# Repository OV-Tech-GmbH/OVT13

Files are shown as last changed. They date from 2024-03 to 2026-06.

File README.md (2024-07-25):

# OVT13
Open-source thin-and-light 13" laptop
## Table of contents

1. Electronics
   - Keyboard PCB
   - Webcam PCB
   - Trackpad PCBs
2. Mechanical
   - Keyboard
3. Software
   - Keyboard firmware and source files

## Details of content

1. Electronics
   - Keyboard PCB: Render01<br /> <br /> 
***General description:*** <br /> <br /> This module is a separate standalone and thinly-designed electromechanical keyboard for the open-source laptop. It provides a distinct hardware abstraction via USB2.0 connectivity to simplify integration into a laptop or computer system. An RP2040 microcontroller constantly evaluates the states of the keyswitches and controls the lightning. Regarding the power supply only a voltage of 5V DC is needed to completly supply the electronics, all other voltages for digital logic and LED-driving are being generated on the PCB. Once connected to an USB Host in a computer system, the microcontroller acts as an USB Device and registers itself as an USB HID keyboard device. With this configuration no custom drivers are needed which contributes to an os-independend (Windows, Linux, etc.) and timeless integration concept. The firmware of the microcontroller is based on the open-source keyboard framework QMK. Once an USB-connection is established, standard scancodes are being transmitted to the computer system which then will be mapped into keycodes. The hardware connectivity to the mainboard of the laptop is realized over an spring-header connector receptable which includes all electrical signals and the power supply. For the firmware to load onto the RP2040, only one pin of the spring header receptable must change its logical state. The RP2040 register itself as an USB-memory device which then can be accessed via the os` filesystem. It is possible to load the firmware file per drag&drop onto the microcontroller. <br /> <br /> 
***Electrical specification***<br /> <br /> 
__PCB front view__
OV_Tech_KB-PCB-R02_3DFront
The PCB-front consists of the keyswitches from the manufacturer Khail. The design integrates a complete set of keys without the numerical part. Keycaps can be assembled on top of the keyswitches.
Inside the keyswitches there is a transparent cabin to integrate LED components and other small components like the anti-ghosting diode. Per keyswitch a white LED and an RGB LED is placed to keep the option to build a keyboard with either white backlightning or RGB backlightning. OV_Tech_KB-PCB-R02_3DCutoutTopComponentPlacement
<br /><br /> __PCB back view__ <br />
On the backside of the PCB there are all remaining components located. The remaing components include the microcontroller RP2040 and its peripheral circuitry, voltage generation, ESD-protection and other parts of the keyswitch matrix.
OV_Tech_KB-PCB-R02_3DBack <br />
<br /> __PCB layerstack and routing__ <br /> The Layerstack consists four layers of copper and it is taken from the 4-Layer JLCPCB stackup JLC04161H-7628. An impedance profile 90Ohms is included for the USB connection. The layerstack looks as follows: Top-layer: Signal, Mid1-layer: GND, Mid2-layer PWR/GND, Bottom-layer: Signal OV_Tech_KB-PCB-LayerstackWithImpedanceProfile
On the top layer all signals and power supplies regarding the LED-backlightning are routed:
OV_Tech_KB-PCB-R02_TopLayer
The Mid1-layer includes a continuous ground plane to provide good electrical characteristics. The Mid2-layer is a mix of power plane distribution and ground islands, especially for the dense placement of the microcontroller and surrounding circuitry:
OV_Tech_KB-PCB-R02_MidLayer2PWRf
On the bottom layer consist of the routing of the keyswitch matrix, the microcontroller and the remaining circuitry.
OV_Tech_KB-PCB-R02_BottomLayer

   - Trackpad PCBs:<br /> <br /> 
***General description:***<br /> <br /> The design of the trackpad module consists of two printed circuit boards. The first one consists of the touch-sensitive matrix which, can be influenced by the user. In order to keep variations and negative impact factors away from the matrix, the touch sensing IC and its digital communication partner are located on an evaluation board. Both boards are connected via an flex-pcb cable section so the touch IC can to read the sensing matrix.<br /> <br /> Trackpad_Sensor_Eval_assembled
<br /> <br />
__1. Trackpad sensor PCB electrical specification:__<br /> <br />
The top side of the PCB consists of touch-sensitive elements in the form of diamonds arranged in rows and columns. The gaps between the diamonds form capacitive elements that can be controlled and thus read by the touch IC. The capacitive elements generate an electric field, that is deflected when the user`s finger approaches. The change in the field and thus the resulting capacitance and charge can be measured and converted into a finger position sensor. <br /> <br />
grafik
<br /> <br />
On the backside of the pcb a flex pcb connector and a snap dome are located. The flex connector is used to connect the board to another board on which a touch IC is located via a flex cable. The snap dome is being used to generate the function of a button press. When pressed, the entire row and colum is shorted and the rapid change in capacitance and therefore charge is recognised and interpreted as a button press. <br /> <br />
grafik
<br /> <br />__2. Trackpad evaluation PCB electrical specification:__<br /> <br />
This PCB is designed as a flex PCB with two stiffened sections. The section where all the components are located is fitted with a FR4-stiffener. The section designed as a flex cable contains no stiffeners in order to utilise the flexibility of a flex cable. The last section is the connector tongue itself and the stiffener is made out of polyimide to fulfil the thickness insertion requierements of the ffc-connector on the trackpad PCB.
<br /> <br />Trackpad Evalboard Board Section View
<br /> <br />
The evaluation board is used to collect trackpad touch data and turn it into an USB HID mouse. This level of integration abstracts the custom interface to a simple USB connection without the need for special drivers or hardware to utilise the touch data. The IQS9150 IC performs the sampling and processing of the trackpad touches and snapdome clicks and reports the data to an RP2040, which performs some further processing, such as interpreting a click event as a left or right mouse button click. The RP2040 streams the touch data in USB HID mouse format to an USB host and thus acts as an I2C USB bridge. Additional connections for programming and evaluating the two ICs and other devices such as test buttons are provided on the board for development purposes. The final board will contain only the two ICs, some necessary external circuitry and an USB connection. This makes integration into the laptop easy and follows the concept of a timeless and modular design.
<br /> <br />
Trackpad Evalboard Board 3D view<br /> <br />

3. Mechanical
   - Keyboard: -

4. Software
   - Keyboard PCB: The firmware of the keyboard was created using the framework QMK. The framework provides all basic keyboard functions such as matrix scanning, USB communication, lightning and much more. Therefore, only one module of the keyboard project has been created for the specific design of the keyboard. Minor modifications were made to the QMK core to compile the firmware for the RP2040 microcontroller. A standard English keyboard layout (QWERTY) was used. Details of the code project can be found in the subfolder for the keyboard software.

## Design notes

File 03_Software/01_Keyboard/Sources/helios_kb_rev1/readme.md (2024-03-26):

# helios_kb_rev1

helios_kb_rev1

*A short description of the keyboard/project*

* Keyboard Maintainer: [ThomasL](https://github.com/ThommyL34)
* Hardware Supported: *The PCBs, controllers supported*
* Hardware Availability: *Links to where you can find this hardware*

Make example for this keyboard (after setting up your build environment):

    make helios_kb_rev1:default

Flashing example for this keyboard:

    make helios_kb_rev1:default:flash

See the [build environment setup](https://docs.qmk.fm/#/getting_started_build_tools) and the [make instructions](https://docs.qmk.fm/#/getting_started_make_guide) for more information. Brand new to QMK? Start with our [Complete Newbs Guide](https://docs.qmk.fm/#/newbs).

## Bootloader

Enter the bootloader in 3 ways:

* **Bootmagic reset**: Hold down the key at (0,0) in the matrix (usually the top left key or Escape) and plug in the keyboard
* **Physical reset button**: Briefly press the button on the back of the PCB - some may have pads you must short instead
* **Keycode in layout**: Press the key mapped to `QK_BOOT` if it is available

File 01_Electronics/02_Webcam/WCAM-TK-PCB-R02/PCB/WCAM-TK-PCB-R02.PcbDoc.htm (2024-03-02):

Reporting Options

# File in Newer Format

Date | : | 06.11.2023
Time | : | 02:03:40
Filename | : | C:\Users\Lukas\OV Tech GmbH\OV Tech GmbH - Cloud\02_Projects\00_Helios\01_Elektronik\01_Module\02_Webcam\WCAM-TK-PCB-R02\PCB\WCAM-TK-PCB-R02.PcbDoc

Version | Warning
Release 23.6 | CAUTION - The PCB document contains Footprint parameters. These will be lost when opening the document in a version of Altium Designer that does not support this functionality.

This file was generated by a later version of the software

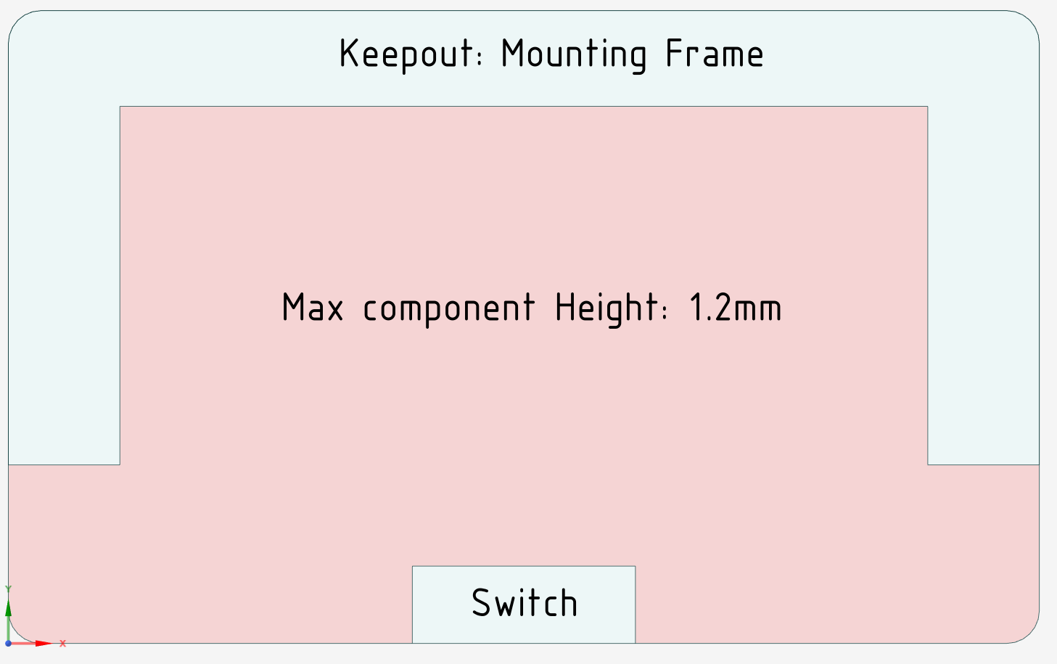
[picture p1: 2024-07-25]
01_Electronics/03_Trackpad/Trackpad sensor/TP-SENSOR-R01/MCAD EXCHANGE/Trackpad_Keepout Zones.png

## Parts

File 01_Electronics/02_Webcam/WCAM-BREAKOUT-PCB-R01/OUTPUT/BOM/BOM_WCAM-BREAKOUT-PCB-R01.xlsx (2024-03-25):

Designator | Quantity | Comment | Manufacturer 1 Prt. Nr. | Manufacturer 2 | Manufacturer 2 Prt. Nr.
C1, C2, C3, C6, C7, C8, C9, C10, C11, C12, C14, C15, C16 | 13 | 1µF 25V | GRM155R61E105KE11D | Walsin | 0402X105K250CT
C4, C5 | 2 | 470nF 25V | GRM155R61E474KE01D | Walsin | 0603X474K250CT
C13 | 1 | 470nF 10V | LMK063BBJ474KPLF | TDK | C0603X5R1A474M030BC
D1, D2 | 2 | ESD7504MUTAG | ESD7504MUTAG
J1 | 1 | SFW15R-1STE1LF | SFW15R-1STE1LF
J2, J3, J5 | 3 | 61300311121 | 61300311121
J4 | 1 | 61301621021 | 61301621021
L1, L2, L3 | 3 | 90Ohm 100mA | DLM0NSM900HY2D
Q1 | 1 | SSM3J56ACT,L3F | SSM3J56ACT,L3F
Q2 | 1 | SSM3K15ACT,L3F | SSM3K15ACT,L3F
Q3 | 1 | DMG1024UV-7 | DMG1024UV-7
Q4, Q5, Q6, Q7, Q8, Q9, Q10, Q11, Q12 | 9 | PMZ130UNEYL | PMZ130UNEYL
R1, R2, R4, R9, R30, R31, R34, R35, R38, R39, R40, R43, R46, R60, R61, R66, R67 | 17 | 0Ohm 1% | CR0402AJ/-000GAS | YAGEO | AC0402FR-070RL
R3, R8 | 2 | 15k 1% | CRCW040215K0FKED | YAGEO | RT0402FRE0715KL
R5, R7, R12, R16, R22, R23, R32, R63 | 8 | 1.5k 1% | CRCW04021K50FKED | YAGEO | RC0402FR-131K5L
R6 | 1 | 240R 1% | CRCW0402240RFKEDC | YAGEO | RC0402FR-13240RL
R10, R11 | 2 | 2.2k 1% | CRCW04022K20FKED | Panasonic | ERJ-2RKF2201X
R13, R18, R20, R24, R25, R29, R47, R59, R65 | 9 | 100R 1% | CRCW0402100RFKEDC | YAGEO | RC0402FR-07100RL
R14, R17, R19, R21, R26, R27, R28, R33, R36, R37, R41, R42, R50, R53, R54, R64, R68 | 17 | 10k 1% | CRCW040210K0FKEDC | YAGEO | RT0402FRE0710KL
R15 | 1 | 27R 1% | RC0402FR-0727RL | TE Connectivity Passive Product | CRGCQ0402F27R
R44, R45, R62 | 3 | 47k 1% | CRCW040247K0FKEDC | YAGEO | RT0402FRE0747KL
R48, R49, R51, R52, R55, R56 | 6 | 200 1% | ERJ-2RKF2000X | Bourns | CR0402-FX-2000GLF
U1 | 1 | OV02740-H34A-Z | OmniVision
U2 | 1 | TLV74018PDQNR | TLV74018PDQNR
U3 | 1 | TLV74012PDQNR | TLV74012PDQNR
U4 | 1 | TLV74028PDQNR | TLV74028PDQNR
U5 | 1 | ECS-2520MV-240-BN-TR | ECS-2520MV-240-BN-TR
U6, U8 | 2 | 74HC2G14GW-Q100 | 74HC2G14GW-Q100
U7 | 1 | TCAL9539RTWR | TCAL9539RTWR

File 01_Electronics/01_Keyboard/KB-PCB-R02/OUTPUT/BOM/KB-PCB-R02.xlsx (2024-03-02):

Designator | Quantity | Manufacturer 1 Prt. Nr. | Manufacturer 2 Prt. Nr.
C1, C3, C5, C6, C7, C8, C9, C12, C13, C14, C15, C18, C22, C26, C27, C28, C29, C30, C31, C32, C33, C34, C35, C36, C37, C38, C39, C40, C41, C42, C43, C44, C45, C46, C47, C48, C49, C50, C51, C54, C55, C56, C57, C58, C59, C60, C61, C62, C63, C64, C65, C66, C67, C68, C69, C70, C71, C72, C73, C74, C75, C76, C77, C78, C79, C80, C81, C82, C83, C84, C85, C86, C87, C88, C89, C90, C91, C92, C93, C94, C95, C96, C97, C98, C99, C100, C101, C102, C103, C104, C105, C106, C107, C108, C109, C115, C116 | 97 | KGM05AR71C104KH | EMK105B7104KV-F
C2, C4, C25 | 3 | CL05A105KO5NNNC | EMK105BJ105KV-F
C10, C11 | 2 | CL21A106KOQNNNG | C0805C106K8PAC7210
C16, C17 | 2 | QSCF500Q270G1GV001T | GJM1555C1H270GB01D
C19, C110, C111, C112, C113, C114 | 6 | GCM1555C1H331FA16J | C0402C331J5GACAUTO
C20, C23 | 2 | GRM21BR61E226ME44K | CC0805MKX5R8BB226
C21, C24, C52, C53 | 4 | GRM188R61E106KA73J | CL10A106MA8NRNC
D1, D2, D3, D4, D5, D6, D7, D8, D9, D10, D11, D12, D13, D14, D15, D16, D17, D18, D19, D20, D21, D22, D23, D24, D25, D26, D27, D28, D29, D30, D31, D32, D33, D34, D35, D36, D37, D38, D39, D40, D41, D42, D43, D44, D45, D46, D47, D48, D49, D50, D51, D52, D53, D54, D55, D56, D57, D58, D59, D60, D61, D62, D63, D64, D65, D66, D67, D68, D69, D70, D71, D72, D73, D74, D75, D76, D77, D78, D79, D80 | 80 | BAT54LS-QYL
D81, D82, D83, D84, D85, D86, D87, D88, D89, D90, D91, D92, D93, D94, D95, D96, D97, D98, D99, D100, D101 | 21 | PESD5V5C1UL
J2_DBG | 1 | SM05B-SRSS-TB
L1 | 1 | MPL-AL4020-3R3
LED1, LED2, LED3, LED4, LED5, LED6, LED7, LED8, LED9, LED10, LED11, LED12, LED13, LED14, LED15, LED16, LED17, LED18, LED19, LED20, LED21, LED22, LED23, LED24, LED25, LED26, LED27, LED29, LED30, LED31, LED32, LED33, LED34, LED35, LED36, LED37, LED38, LED39, LED40, LED41, LED42, LED43, LED44, LED45, LED46, LED47, LED48, LED49, LED50, LED51, LED52, LED53, LED54, LED55, LED57, LED58, LED59, LED60, LED61, LED62, LED63, LED64, LED65, LED66, LED67, LED68, LED69, LED70, LED71, LED72, LED73, LED74, LED75, LED76, LED77, LED78, LED79, LED80, LED81, LED82, LED83, LED85 | 82 | HL-PT-1608H322W-L
LED86, LED87, LED88, LED89, LED90, LED91, LED92, LED93, LED94, LED95, LED96, LED97, LED98, LED99, LED100, LED101, LED102, LED104, LED105, LED106, LED107, LED108, LED109, LED110, LED111, LED113, LED114, LED115, LED116, LED117, LED118, LED119, LED120, LED122, LED123, LED124, LED125, LED126, LED127, LED128, LED129, LED130, LED131, LED132, LED133, LED134, LED135, LED136, LED137, LED138, LED139, LED140, LED141, LED142, LED143, LED144, LED145, LED146, LED147, LED148, LED149, LED150, LED151, LED152, LED153, LED154, LED155, LED156, LED157, LED158, LED159, LED160, LED161, LED162, LED163, LED164, LED165, LED166, LED167, LED168, LED169 | 81 | SK6805-EC15
Q2 | 1 | PMG85XP,115
Q3, Q4, U4 | 3 | SSM3K15ACT,L3F
R1, R2 | 2 | RC0402FR-0727RL | CRGCQ0402F27R
R3, R4, R5, R6, R7, R8, R49 | 7 | CRCW040210K0FKEDC | RT0402FRE0710KL
R9, R11 | 2 | CRCW04021K00FKEDC | RT0402FRE131KL
R10 | 1 | CRCW040210K0FKEDC | RT0402FRE0710KL
R12, R13, R14, R15, R16, R17, R18, R19 | 8 | CR0402AJ/-000GAS | AC0402FR-070RL
R20, R21, R63 | 3 | CRCW0402100KFKEDC | RC0402FR-07100KL
R22, R23, R24, R25, R26, R27, R28, R29, R30, R31, R32, R33, R34, R35, R36, R37, R38, R39, R40, R41, R42, R43, R44, R45, R46, R47, R48 | 27 | RC0603FR-07113RL | ERJ-3EKF1130V
R50, R51, R57, R60, R64, R65 | 6 | CRCW0402100RFKEDC | RC0402FR-07100RL
R52, R53, R55, R59, R66, R168 | 6 | CRCW040247K0FKEDC | RT0402FRE0747KL
R54 | 1 | ERJ-3EKF88R7V | CR0603-FX-88R7ELF
R56 | 1 | CRCW0402130KFKED | CRCW0402750KFKEDC
R58 | 1 | CR0402-FX-6802GLF | SFR01MZPJ683
R61, R62, R67, R68, R69, R70, R71, R72, R73, R74, R75, R76, R77, R78, R79, R80, R81, R82, R83, R84, R85, R86, R87, R88, R89, R90, R91, R92, R93, R94, R95, R96, R97, R98, R99, R100, R101, R102, R103, R104, R105, R106, R107, R108, R109, R110, R111, R112, R113, R114, R115, R116, R117, R118, R119, R120, R121, R122, R123, R124, R125, R126, R127, R128, R129, R130, R131, R132, R133, R134, R135, R136, R137, R138, R139, R140, R141, R142, R143, R144, R145, R146 | 82 | CRCW0402470RFKED | RC0402FR-13470RL
R147, R148, R149, R150, R151, R152, R153, R154, R155, R156, R157, R158, R159, R160, R161, R162, R163, R164, R165, R166, R167 | 21 | ERJ-2RKF3000X | SFR01MZPJ301
SW1, SW2, SW3, SW4, SW5, SW6, SW7, SW8, SW9, SW10, SW11, SW12, SW13, SW14, SW15, SW16, SW17, SW18, SW19, SW20, SW21, SW22, SW23, SW24, SW25, SW26, SW27, SW28, SW29, SW30, SW31, SW32, SW33, SW34, SW35, SW36, SW37, SW38, SW39, SW40, SW41, SW42, SW43, SW44, SW45, SW46, SW47, SW48, SW49, SW50, SW51, SW52, SW53, SW54, SW55, SW56, SW57, SW58, SW59, SW60, SW61, SW62, SW63, SW64, SW65, SW66, SW67, SW68, SW69, SW70, SW71, SW72, SW73, SW74, SW75, SW76, SW77, SW78, SW79, SW80, SW81 | 81 | CPG1316S01D02
U1 | 1 | RP2040
U2 | 1 | TLV74033PDQNR
U3 | 1 | W25Q16JVUXIQ
U5 | 1 | MP3438
U6, U7 | 2 | 74HC2G14GV-Q100H
XTAL1 | 1 | H130B-12.000-18-3030-TR

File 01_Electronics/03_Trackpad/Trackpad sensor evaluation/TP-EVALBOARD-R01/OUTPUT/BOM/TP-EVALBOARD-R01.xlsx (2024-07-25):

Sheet: Header
PCB Bill Of Material
Project: | Helios
PCB: | TP-EVALBOARD
Revision: | Rev. 0.1
Scope: | Open-Source
License: | CERN-OHL-S-2.0
Date of publishing: | 17.07.2024

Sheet: List
# | Designator | Quantity | Comment | Manufacturer 1 | Manufacturer 1 Prt. Nr. | Manufacturer 2 | Manufacturer 2 Prt. Nr.
1 | C1, C2 | 2 | 10µF 16V | Samsung Electro-Mechanics | CL21A106KOQNNNG | KEMET | C0805C106K8PAC7210
2 | C3, C4, C5, C6, C7, C8, C10, C11, C12, C13, C14, C17, C20, C25, C26 | 15 | 100nF 25V | KYOCERA AVX | KGM05AR71C104KH | Taiyo Yuden | EMK105B7104KV-F
1 | C9, C15 | 2 | 1µF 16V | Samsung Electro-Mechanics | CL05A105KO5NNNC | Taiyo Yuden | EMK105BJ105KV-F
2 | C16, C19 | 2 | 100pF 50V | Murata Electronics | GRT1555C1H101JA02D | YAGEO | CC0402JPNPO9BN101
1 | C18, C21, C22 | 3 | 22µF 25V | Murata Electronics | GRM21BR61E226ME44K | YAGEO | CC0805MKX5R8BB226
2 | C23, C24 | 2 | 13pF 50V | Murata Electronics | GRT1555C1H130FA02D | YAGEO | CQ0402FRNPO9BN130
1 | J1 | 1 | 61300211121 | Würth elektronik | 61300211121
2 | J2 | 1 | 629105136821 | Würth Elektronik
1 | J4 | 1 | SM05B-SRSS-TB | JST | SM05B-SRSS-TB
2 | J5 | 1 | 61231020621 | Würth Elektronik | 61231020621
1 | R1, R2, R6, R9, R26 | 5 | 1k 1% | Vishay / Dale | CRCW04021K00FKEDC | YAGEO | RT0402FRE131KL
2 | R3, R4, R5, R27 | 4 | 0Ohm 1% | Bourns | CR0402AJ/-000GAS | YAGEO | AC0402FR-070RL
1 | R7, R8 | 2 | 27R 1% | YAGEO | RC0402FR-0727RL | TE Connectivity Passive Product | CRGCQ0402F27R
2 | R10, R11, R12, R24 | 4 | 4k7 1% | Vishay / Dale | CRCW04024K70FKEDC | Panasonic | ERJ-PA2F4701X
1 | R13, R14, R15, R16, R17, R18, R19, R20, R21, R22, R23, R25 | 12 | 100R 1% | Vishay / Dale | CRCW0402100RFKEDC | YAGEO | RC0402FR-07100RL
2 | R28 | 1 | 10k 1% DNP | Vishay / Dale | CRCW040210K0FKEDC | YAGEO | RT0402FRE0710KL
1 | SW1, SW2, SW3, SW4, SW5, SW6 | 6 | PTS815 SJM 250 SMTR LFS | C&K | PTS815 SJM 250 SMTR LFS
2 | U1 | 1 | TLV74033PDQNR | Texas Instruments | TLV74033PDQNR
1 | U2 | 1 | RP2040 | Raspberry Pi Foundation | RP2040
2 | U3 | 1 | IQS9150 | Azoteq | IQS9150-000QFR
1 | U4 | 1 | W25Q16JVUXIQ | Winbond | W25Q16JVUXIQ
2 | XTAL1 | 1 | ECX-2236B | ECS | ECS-120-10-36B-CWY-TR3

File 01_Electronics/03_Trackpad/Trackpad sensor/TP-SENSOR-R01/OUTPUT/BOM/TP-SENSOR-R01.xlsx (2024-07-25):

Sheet: Header
PCB Bill Of Material
Project: | Helios
PCB: | Trackpad Sensor PCB 15x10
Revision: | Rev0.1
Scope: | Open-source
License: | CERN-OHL-S-2.0
Date of publishing: | 13.07.2024

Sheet: List
# | Designator | Quantity | Comment | Manufacturer 1 | Manufacturer 1 Prt. Nr. | #Column Name Error:' Manufacturer 2 | #Column Name Error:' Manufacturer 2 Prt. Nr.
1 | J1 | 1 | FH35C-33S-0.3SHW | Hirose Connector | FH35C-33S-0.3SHW(99)
2 | SW_SNAP | 1 | RCG05200N | Snaptron Inc | RCG05200N
3

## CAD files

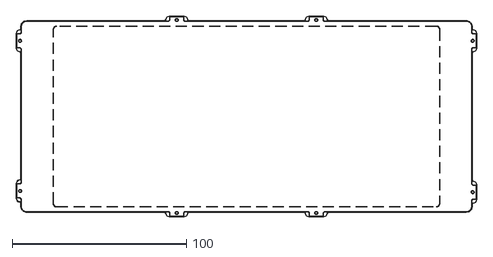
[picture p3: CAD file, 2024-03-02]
01_Electronics/01_Keyboard/KB-PCB-R02/MCAD EXCHANGE/Keyboard component keepout.dxf
263.8 x 114.7

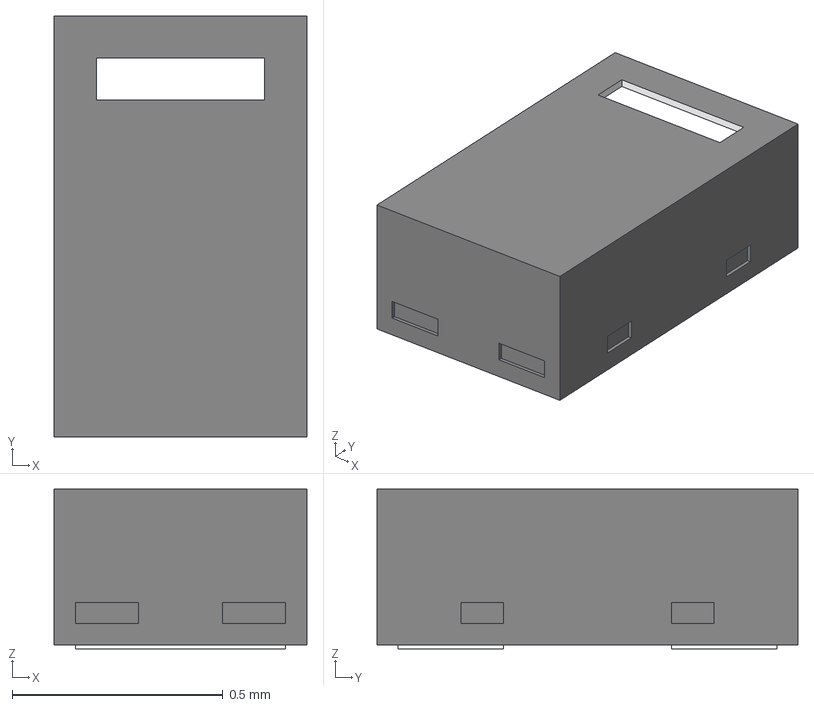
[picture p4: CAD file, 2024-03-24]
01_Electronics/01_Keyboard/KB-PCB-R02_KiCad/ALTIUM_EMBEDDED_MODELS/SOD-882.STEP
0.6 x 1.00 x 0.38 mm

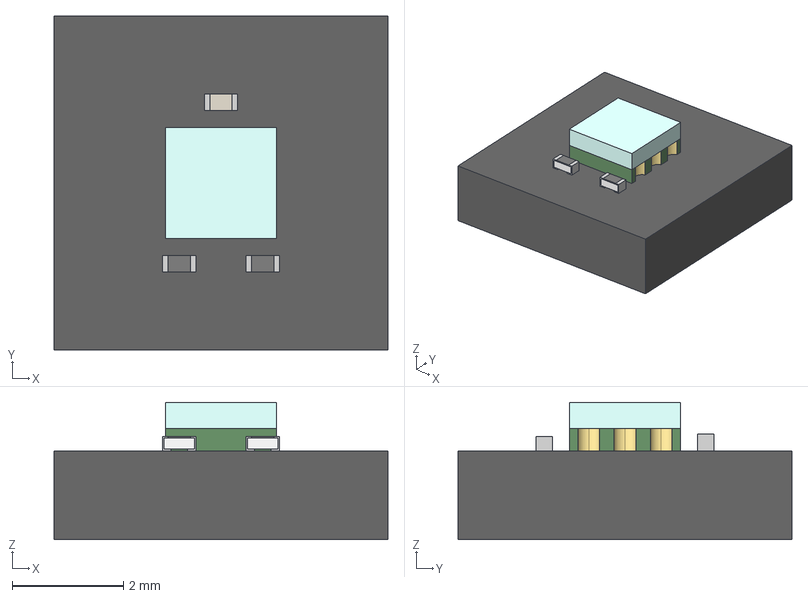
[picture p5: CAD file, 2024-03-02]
01_Electronics/02_Webcam/ABLS-PCB-R01/OUTPUT/3D Models/ABLS-PCB-R01.step
6.00 x 6.00 x 2.46 mm
IC
Carrier
Verguss

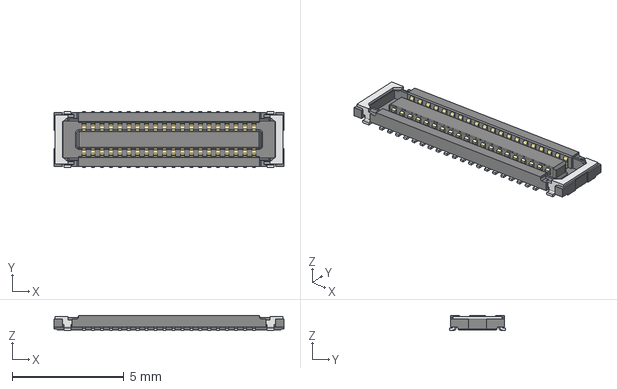
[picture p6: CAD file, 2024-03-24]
01_Electronics/02_Webcam/KiCad WCAM-TK-PCB-R02/ALTIUM_EMBEDDED_MODELS/BTB_40P_04mm_5055504020.stp
10.3 x 2.50 x 0.66 mm

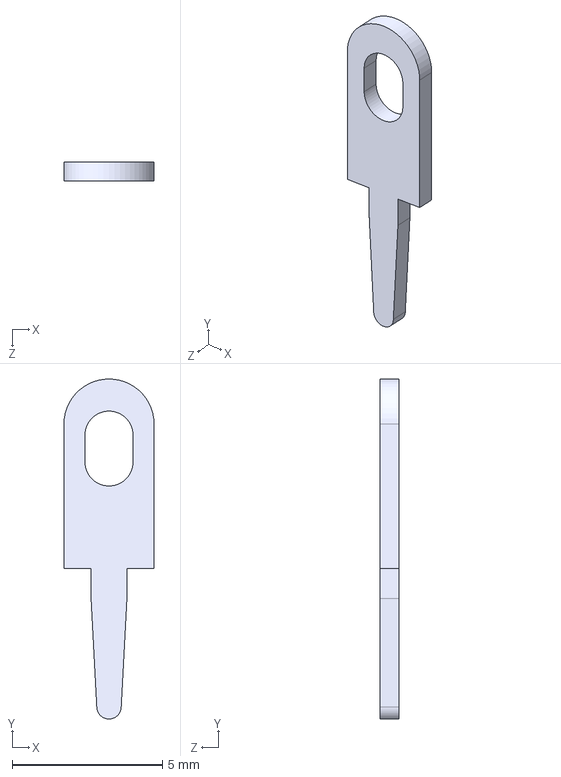
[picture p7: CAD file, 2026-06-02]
01_Electronics/02_Webcam/WCAM-BREAKOUT-PCB-R03/PCB/ALTIUM_EMBEDDED_MODELS/4952--3DModel-STEP-630548.STEP
3.00 x 11.3 x 0.635 mm

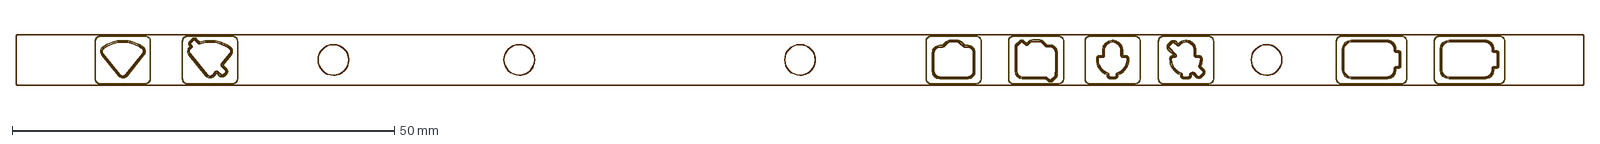
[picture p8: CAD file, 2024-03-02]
01_Electronics/02_Webcam/WCAM-TK-PCB-R02/MCAD EXCHANGE/Touch FPC Outline.dxf
205.0 x 6.60 mm

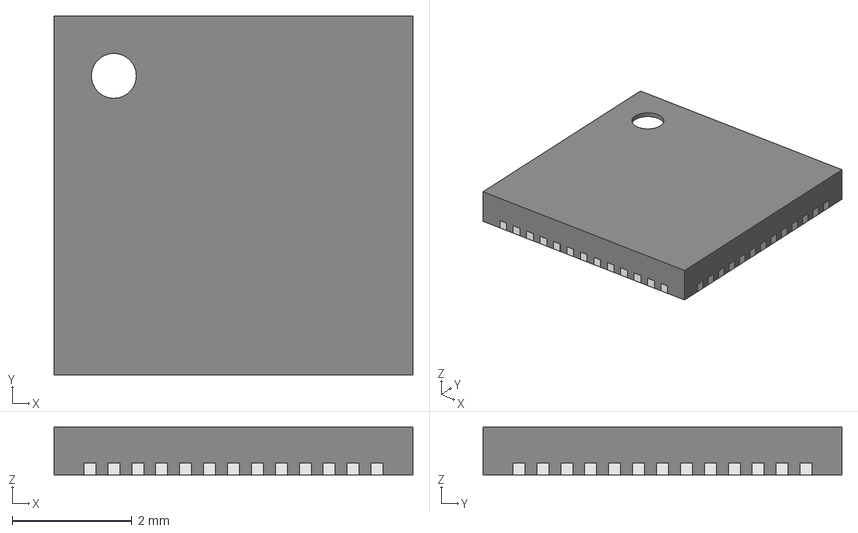
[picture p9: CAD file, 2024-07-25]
01_Electronics/03_Trackpad/Trackpad sensor evaluation/TP-EVALBOARD-R01_KiCad/ALTIUM_EMBEDDED_MODELS/QFN40P600X600X80_HS-53M.step
6.00 x 6.00 x 0.801 mm
Thermal Shape

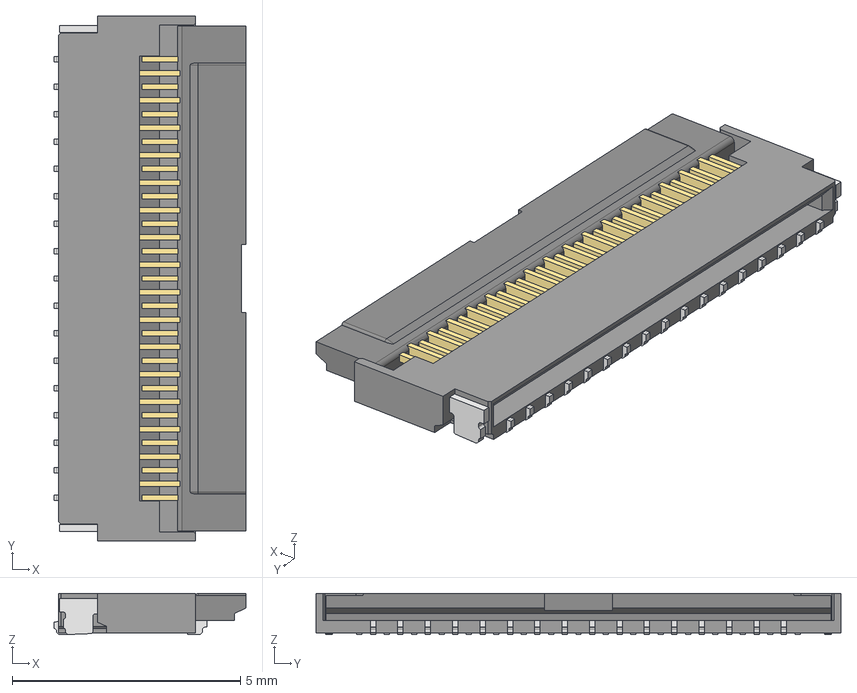
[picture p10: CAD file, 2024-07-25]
01_Electronics/03_Trackpad/Trackpad sensor/TP-SENSOR-R01_KiCad/ALTIUM_EMBEDDED_MODELS/FPC_33pol_FH35-33S-0.3SHW.stp
4.20 x 11.5 x 0.9 mm

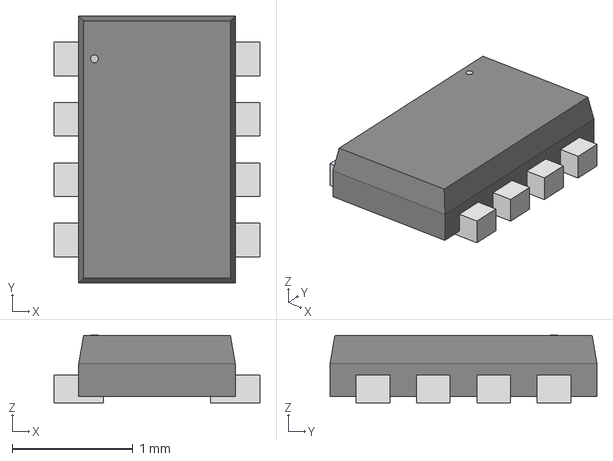
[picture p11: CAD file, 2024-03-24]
01_Electronics/01_Keyboard/KB-PCB-R02_KiCad/ALTIUM_EMBEDDED_MODELS/SOT583_MP3438_MNP.step
1.70 x 2.21 x 0.561 mm

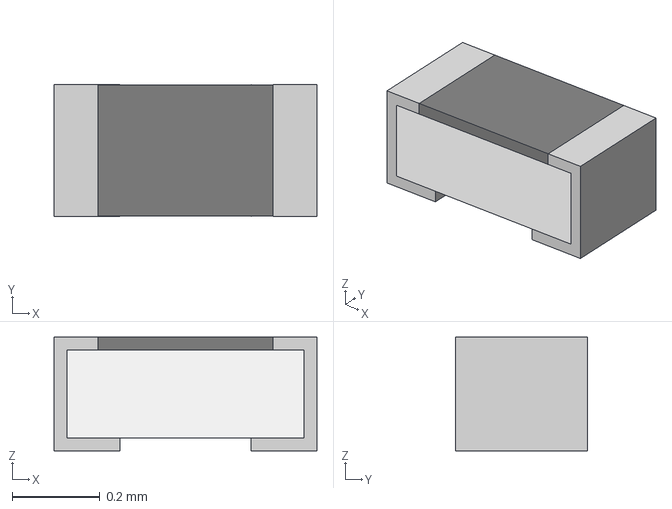
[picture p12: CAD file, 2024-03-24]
01_Electronics/02_Webcam/KiCad WCAM-TK-PCB-R02/ALTIUM_EMBEDDED_MODELS/RES_0201_m0603.stp
0.6 x 0.3 x 0.26 mm

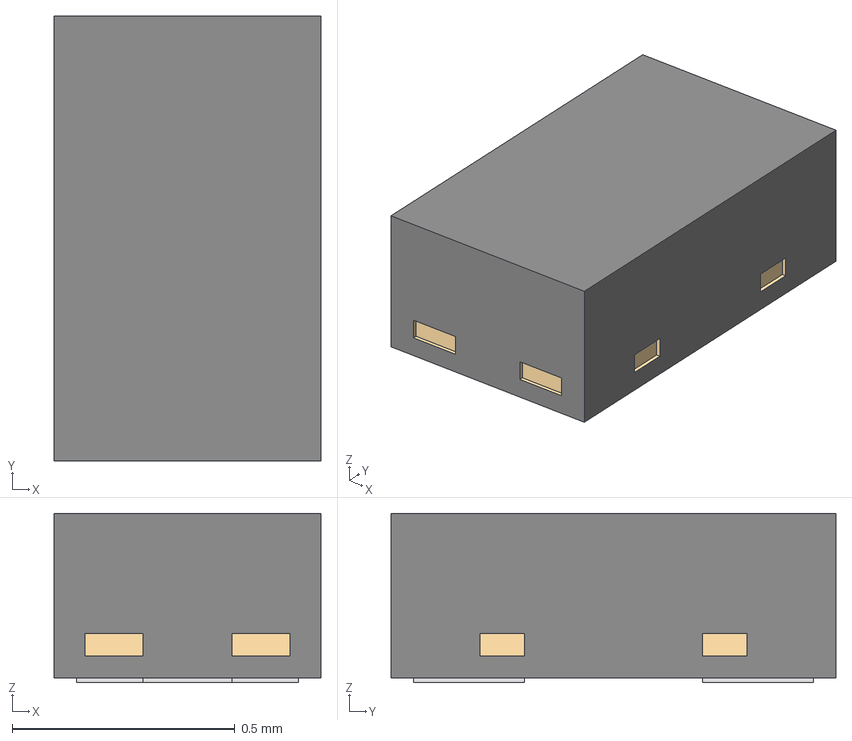
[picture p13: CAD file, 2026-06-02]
01_Electronics/02_Webcam/WCAM-BREAKOUT-PCB-R03/PCB/ALTIUM_EMBEDDED_MODELS/CST3.stp
0.6 x 1.00 x 0.38 mm

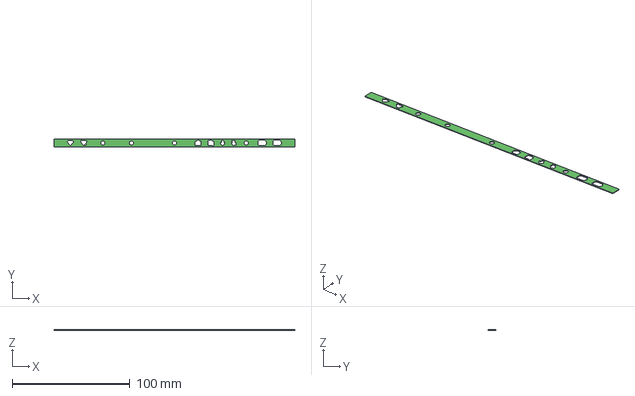
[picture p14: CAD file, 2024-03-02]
01_Electronics/02_Webcam/WCAM-TK-PCB-R02/MCAD EXCHANGE/WCAM-TOUCH-FPC-R01.step
205.0 x 6.60 x 0.411 mm

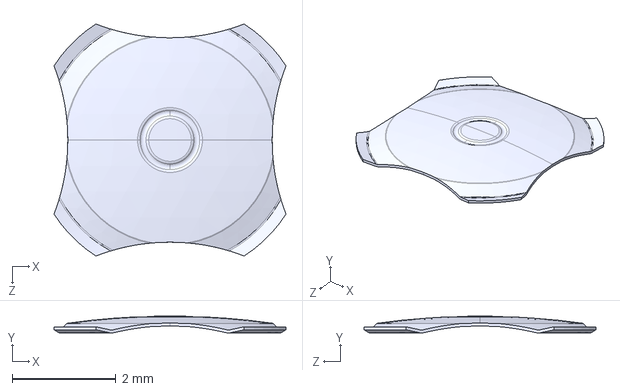
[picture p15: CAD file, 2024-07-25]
01_Electronics/03_Trackpad/Trackpad sensor/TP-SENSOR-R01_KiCad/ALTIUM_EMBEDDED_MODELS/DOME-RCG05200N.STEP
4.47 x 0.325 x 4.47 mm

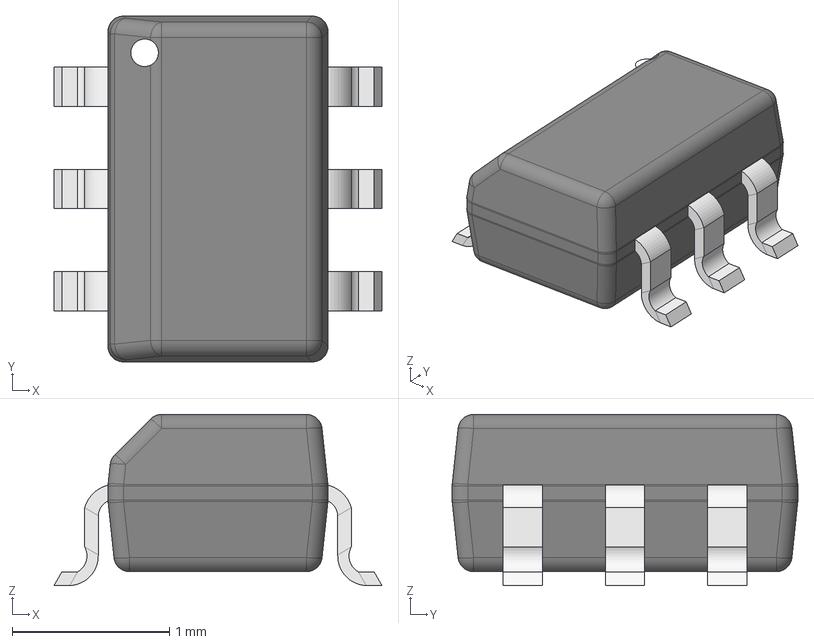
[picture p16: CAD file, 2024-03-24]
01_Electronics/01_Keyboard/KB-PCB-R02_KiCad/ALTIUM_EMBEDDED_MODELS/TSOP65P210X110-6N.step
2.09 x 2.20 x 1.09 mm
Leader x 6

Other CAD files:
01_Electronics/03_Trackpad/Trackpad sensor/TP-SENSOR-R01/MCAD EXCHANGE/Trackpad_outline.dxf
01_Electronics/02_Webcam/KiCad WCAM-TK-PCB-R02/ALTIUM_EMBEDDED_MODELS/ABLS-PCB-R01.stp
01_Electronics/02_Webcam/WCAM-BREAKOUT-PCB-R03/PCB/ALTIUM_EMBEDDED_MODELS/SOT95P275X110-5N.step
01_Electronics/02_Webcam/WCAM-TK-PCB-R02/MCAD EXCHANGE/WCAM-PCB-Outline.dxf
01_Electronics/01_Keyboard/KB-PCB-R02_KiCad/ALTIUM_EMBEDDED_MODELS/0603 Chip SMD LED (1.6x0.8mm).STEP
01_Electronics/01_Keyboard/KB-PCB-R02_KiCad/ALTIUM_EMBEDDED_MODELS/CPG1316S01D02.2.stp
01_Electronics/01_Keyboard/KB-PCB-R02_KiCad/ALTIUM_EMBEDDED_MODELS/ECS-143-18-30BQ-DS.STEP
01_Electronics/01_Keyboard/KB-PCB-R02_KiCad/ALTIUM_EMBEDDED_MODELS/MPL-AL4020-xxx.STEP
01_Electronics/01_Keyboard/KB-PCB-R02_KiCad/ALTIUM_EMBEDDED_MODELS/QFN40P700X700X90_HS-57M.step
01_Electronics/01_Keyboard/KB-PCB-R02_KiCad/ALTIUM_EMBEDDED_MODELS/RES_0603_m1608.stp
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

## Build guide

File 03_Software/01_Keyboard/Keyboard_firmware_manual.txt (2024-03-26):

MANUAL FOR KEYBOARD FIRMWARE DEVELOPMENT AND FLASHING

The firmware is based on QMK (Quantum Mechanical Keyboard)

#1 How to flash the compiled file onto the KB-MCU (RP2040):
	* Precompiled file: helios_kb_rev1_default_20240326.uf2
	* Recompiled (and changed) see: #2
1. Connect pin 7 of J_IN1 to GND
2. Connect the keyboard with your computer over USB (ie. solder the ends of an USB cable to J_IN1, an USB-drive should appear in the hardware drive list)
3. Drag and drop the .uf2 into the USB-drive
4. Disconnect pin 7 of J_IN1 to GND
5. Repower the keyboard (i.e. disconnect the USB connection)
6. Connected over USB the keyboard will appear as a USB device and will provide input to the computer if buttons are being pressed.
7. Enjoy using the hardware!

#2 How to compile the keyboard project:

Info: The project was developed and tested under Windows 11.

1. Download and install the QMK-Firmware (external links)
	* Worked on version: https://github.com/qmk/qmk_distro_msys/releases/tag/1.7.2,
    * Newest version (untested) https://github.com/qmk/qmk_distro_msys/releases/latest

2. Follow these steps https://docs.qmk.fm/#/newbs_getting_started
3. Create a new project with the steps from https://docs.qmk.fm/#/newbs_building_firmware?id=create-a-new-keymap
	* Name the keyboard project: helios_kb_rev1
	* Copy the contents of helios_kb_rev1_20240326.zip into the project folder and replace existing files
4. To apply underlaying changes outside the project folder replace the folders quantum and platforms from the quantum.zip and platforms.zip

5. Edit the the files in the project folder (For detailed information see the official QMK docs)

6. Compile the project with QMK MSYS and the following command: "qmk compile -kb helios_kb_rev1 -km default"

7. To flash the compiled file see #1

26.03.2024
OV Tech GmbH
External links provided are third party 

#3 Keyboard-bindings for lighting up the LEDS (Assuming full component placement regarding the keyboard-BOM):
(Flash the provided .uf2 file onto the MCU first under #1)
* F2: Toggle W-LEDs
* F3: Increase WLED intensity
* F4: Decrease WLED intensity
* F6: Toggle RGB-LEDs
* F7: Increase RGB-LED value intensity (HS V)
* F8: Decrease RGB-LED value intensity (HS V)
* F9: Increase RGB-LED saturation intensity (H S V)
* F10: Decrease RGB-LED hue intensity (H S V)
* F11: Increase RGB-LED saturation intensity (H SV)
* F12: Decrease RGB-LED saturation intensity (H SV)

(There are multiple animation modes available https://docs.qmk.fm/#/feature_rgblight)

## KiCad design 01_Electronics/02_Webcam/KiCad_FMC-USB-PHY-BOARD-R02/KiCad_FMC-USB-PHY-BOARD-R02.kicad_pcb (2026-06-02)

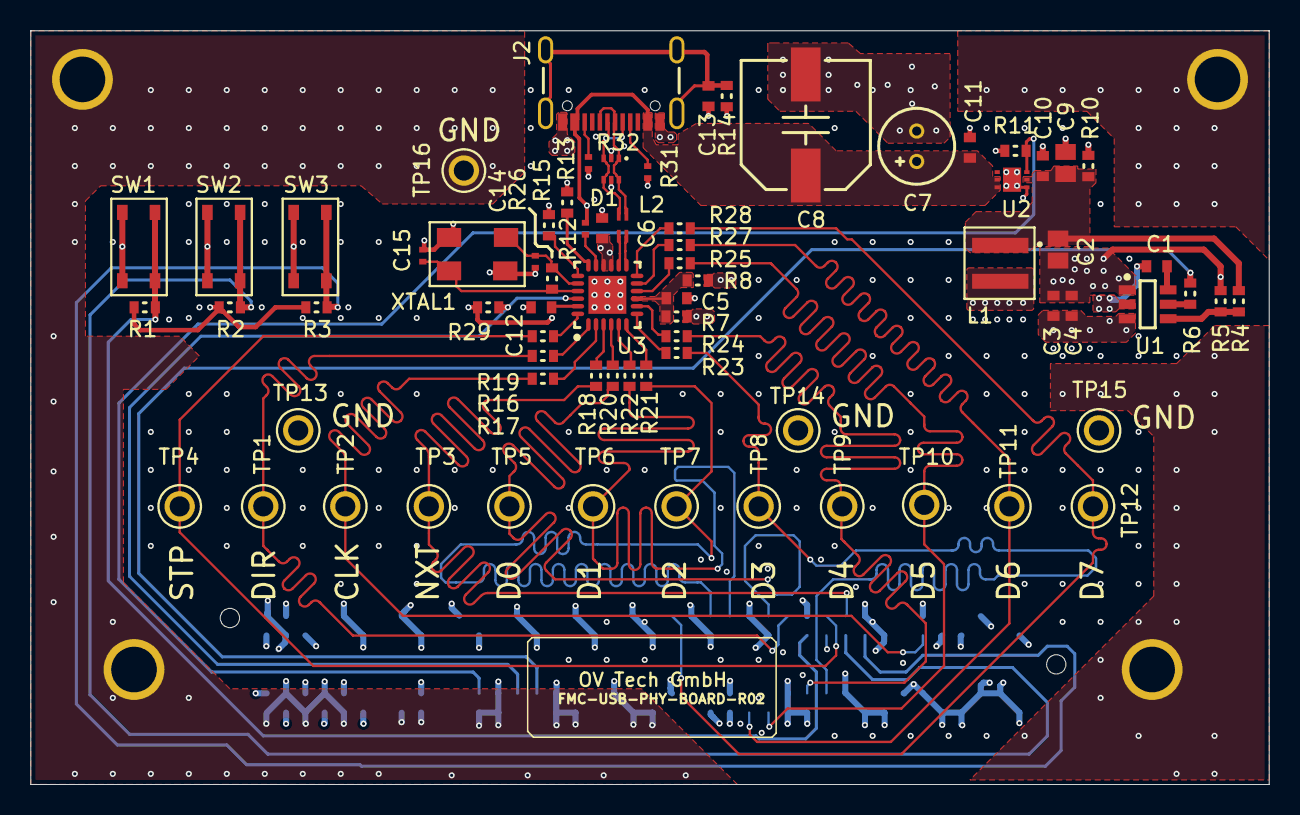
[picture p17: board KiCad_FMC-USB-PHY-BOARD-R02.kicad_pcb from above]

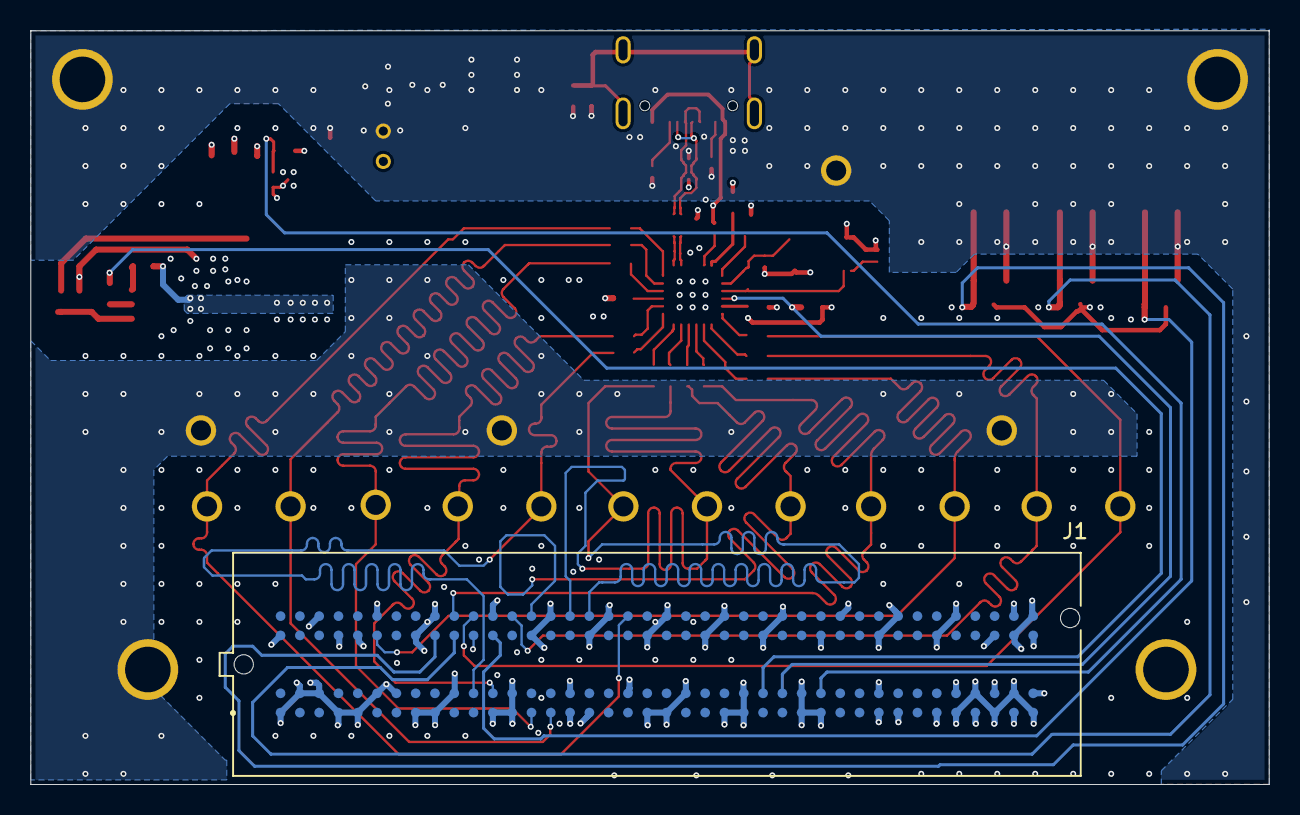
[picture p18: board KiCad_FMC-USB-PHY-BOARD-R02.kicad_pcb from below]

Board: 4 copper layers, 81.5 x 49.6 mm, 77 parts (3 on the bottom side), 54 nets.

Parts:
C1, C4, C5, C10, C11, C13: 100nF 100V; CAPC1608X10L
C2: 33µF 10V; CAPC2012X14L
C3: 2.2µF 35V; CAPC1608X10L
C6, C12: 1µF 16V; CAPC1608X10L
C7: 100µF 10V; CAP_Radial_5x8mm
C8: 22µF 63V; CAPAE9083X70N
C9: 10µF 16V; CAPC2012X14L
C14, C15: 30pF 50V; CAPC1005X06L
D1: 82400152; WE-TVS_SOT563
J1: ASP-134604-01; BOARD-TO-BOARD CON SAMTEC_ASP-134604-01
J2: TYPE-C 16PIN 2MD(073); USB Type C - TYPE-C 16PIN 2MD(073)
L1: 6.8µH 3.75A; WE-MAPI_4030
L2: 90Ohm 100mA; WE-CNSW_0603
MP1, MP2, MP3, MP4: MP_MOUNT_3MM_Plated; MP_3MM_PLATED
R1, R2, R3, R11, R29: 22kOhm 1%; RESC1608X04L
R4: 100kOhm 1%; RESC1608X04L
R5: 13.7kOhm 1%; RESC1608X04L
R6, R7, R8, R13, R16, R18, R19, R20, R21, R22, R23, R24, R25, R27, R28: 0 Ohm; RESC1608X04L
R10: 10kOhm 1%; RESC1608X04L
R12: 10k 1%; RESC1005X04L
R14: 330Ohm 1%; RESC1608X04L
R15: 8.06kOhm 1%; RESC1608X04L
R17: 33Ohm 1%; RESC1608X04L
R26: 1MOhm 1%; RESC1608X04L
R31, R32: 5.1k 1%; RESC1005X04L
SW1, SW2, SW3: PTS815 SJM 250 SMTR LFS; SW_TACT_PTS815 SJM 250 SMTR LFS
TP1, TP2, TP3, TP4, TP5, TP6, TP7, TP8, TP9, TP10, TP11, TP12, TP13, TP14, TP15, TP16: 4952; TP_KEYSTONE_4952
U1: TPS54308DDC; SOT95P280X110-6N
U2: AP21510FM-7; QFN50P201X181X60_HS-7N
U3: USB3343; QFN50P400X400X100_HS-25M
XTAL1: ECS-260-18-30B-AGM-TR; XTAL_ECX-53B_5X3.2X0.85

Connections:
1V8_ADJ: J1.G39, J1.H40, R1.2, R2.2, R3.2, R7.2, R29.2
3V3: C6.1, J1.C39, J1.D32, J1.D36, J1.D38, J1.D40, R8.2, R13.2, U3.15, U3.16
5V0: C2.1, C9.1, C10.1, L1.1, R4.1, R10.2, U2.2
12V0: C3.1, C4.1, J1.C35, J1.C37, U1.3
DEBUG_SW1: J1.G12, R1.1, SW1.3, SW1.4
DEBUG_SW2: J1.G10, R2.1, SW2.3, SW2.4
DEBUG_SW3: J1.G9, R3.1, SW3.3, SW3.4
GND: C2.2, C3.2, C4.2, C5.2, C6.2, C7.2, C8.2, C9.2, C10.2, C11.2, C12.2, C13.2, C14.2, C15.2, D1.2, J1.C1, J1.C4, J1.C5, J1.C8, J1.C9, J1.C12, J1.C13, J1.C16, J1.C17, J1.C20, J1.C21, J1.C24, J1.C25, J1.C28, J1.C29, J1.C32, J1.C33, J1.C36, J1.C38, J1.C40, J1.D2, J1.D3, J1.D6, J1.D7, J1.D10, J1.D13, J1.D16, J1.D19, J1.D22, J1.D25, J1.D28, J1.D37, J1.D39, J1.G1, J1.G4, J1.G5, J1.G8, J1.G11, J1.G14, J1.G17, J1.G20, J1.G23, J1.G26, J1.G29, J1.G32, J1.G35, J1.G38, J1.G40, J1.H3, J1.H6, J1.H9, J1.H12, J1.H15, J1.H18, J1.H21, J1.H24, J1.H27, J1.H30, J1.H33, J1.H36, J1.H39, J2.A1/B12, J2.A12/B1, MP1.1, MP2.1, MP3.1, MP4.1, R5.1, R10.1, R11.1, R14.1, R15.2, R31.1, R32.1, SW1.1, SW1.2, SW2.1, SW2.2, SW3.1, SW3.2, TP13.TP, TP14.TP, TP15.TP, TP16.TP, U1.1, U2.1, U2.7, U3.25, XTAL1.2, XTAL1.4
NetC1_1: C1.1, U1.6
NetC1_2: C1.2, L1.2, U1.2
NetC5_1: C5.1, R7.1, R8.1, U3.9
NetC12_1: C12.1, U3.23
NetC13_1: C13.1, J2.SHD, R14.2
NetJ2_A5: J2.A5, R31.2
NetJ2_B5: J2.B5, R32.2
NetR4_2: R4.2, R5.2, U1.4
NetR6_2: R6.2, U1.5
NetR12_1: R12.1, U3.17
NetR13_1: R13.1, U3.18
NetR16_2: R16.2, U3.1
NetR17_2: R17.2, U3.2
NetR18_2: R18.2, U3.3
NetR19_2: R19.2, U3.24
NetR20_2: R20.2, U3.4
NetR21_2: R21.2, U3.5
NetR22_2: R22.2, U3.6
NetR23_2: R23.2, U3.7
NetR24_2: R24.2, U3.8
NetR25_2: R25.2, U3.10
NetR27_2: R27.2, U3.11
NetR28_2: R28.2, U3.12
USB_ESD_N: D1.3, D1.4, J2.A7, J2.B7, L2.2
USB_ESD_P: D1.1, D1.6, J2.A6, J2.B6, L2.3
USB_N: L2.1, U3.14
USB_P: L2.4, U3.13
USB_PHY_RST: J1.D27, R29.1, U3.22
USB_RBIAS: R15.1, U3.19
USB_ULPI_CLK: J1.G6, R17.1, TP2.TP
USB_ULPI_D0: J1.H14, R20.1, TP5.TP
USB_ULPI_D1: J1.H16, R21.1, TP6.TP
USB_ULPI_D2: J1.H17, R22.1, TP7.TP
USB_ULPI_D3: J1.D11, R23.1, TP8.TP
USB_ULPI_D4: J1.D12, R24.1, TP9.TP
USB_ULPI_D5: J1.C14, R25.1, TP10.TP
USB_ULPI_D6: J1.C15, R27.1, TP11.TP
USB_ULPI_D7: J1.H19, R28.1, TP12.TP
USB_ULPI_DIR: J1.H13, R16.1, TP1.TP
USB_ULPI_NXT: J1.H10, R18.1, TP3.TP
USB_ULPI_STP: J1.H11, R19.1, TP4.TP
USB_VBUS_DISABLE: J1.D26, R6.1
USB_XTAL_IN: C15.1, R26.2, U3.21, XTAL1.3
USB_XTAL_OUT: C14.1, R26.1, U3.20, XTAL1.1
VBUS: C7.1, C8.1, C11.1, D1.5, J2.A4/B9, J2.A9/B4, R12.2, U2.5, U2.6
VBUS_EN: J1.D29, R11.2, U2.3

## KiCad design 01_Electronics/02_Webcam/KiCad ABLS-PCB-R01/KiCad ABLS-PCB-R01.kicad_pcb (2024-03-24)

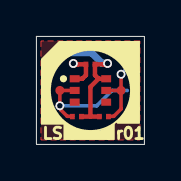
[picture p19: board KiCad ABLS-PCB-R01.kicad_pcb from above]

Board: 2 copper layers, 6.0 x 6.0 mm, 9 parts (1 on the bottom side), 4 nets.

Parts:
C1: 470nF 10V; CAPC0603X03L
R1, R2: 2.1k 1%; RESC0603X03L
TP1, TP2, TP3, TP4: Testpoint 0.5mm; TP_0.50mm
U1: VEML3235; Light Sensor_VEML3235
U2: Ambient Light Sensor Module; ABLS-R01-sensor-Module Footprint

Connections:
GND: C1.2, TP2.TP, U1.1, U2.2, U2.3, U2.4
SCL: R2.1, TP4.TP, U1.5, U2.6
SDA: R1.1, TP3.TP, U1.2, U2.5
VCCA3.3: C1.1, R1.2, R2.2, TP1.TP, U1.6, U2.1

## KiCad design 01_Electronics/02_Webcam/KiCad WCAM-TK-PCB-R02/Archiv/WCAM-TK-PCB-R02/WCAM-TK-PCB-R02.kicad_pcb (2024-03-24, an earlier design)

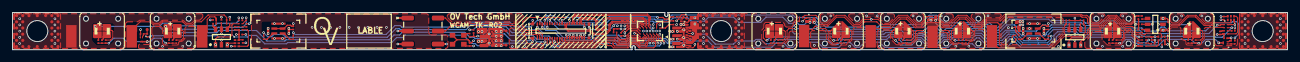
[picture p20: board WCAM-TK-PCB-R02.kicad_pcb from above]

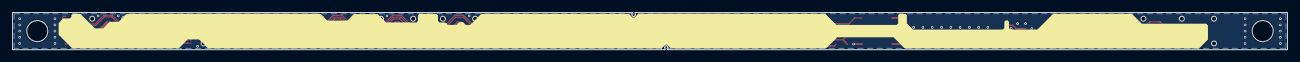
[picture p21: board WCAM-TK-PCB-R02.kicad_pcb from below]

Board: 6 copper layers, 206.0 x 6.0 mm, 179 parts (26 on the bottom side), 113 nets.

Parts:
C1, C2, C5, C6: 1µF 25V; CAPC1005X06L
C3, C4: 10µF 10V; CAPC1005X06L
C7, C10, C11, C12, C15, C16, C17, C20, C21, C22, C23, C26, C27, C35: 470nF 10V; CAPC0603X03L
C8, C9, C13, C14, C18, C19: OPT; CAPC0603X03L
C24, C25, C28, C29, C30, C31, C32, C33, C34: 1uF 6.3V; CAPC0603X03L
J1: 5055504020; BOARD-TO-BOARD 40POL_505550-4020
J2, J3, J4, J5, J6, J7, J8, J9: Custom Light Pipe Diffusor; LIGHT_PIPE_DIFFUSOR_CUSTOM
J10, J11, J14, J15, J18, J19, J22: 3-2199250-3; Contact Pad_3.2mm_3-2199250-3
J12, J16, J20: 74AUP1G14GM,115; PSON50P140X100X50-6L
J13, J17, J21: 74AUP1G74GT,115; PSON50P100X50-8L
LED1, LED2, LED3, LED4, LED5, LED6, LED7, LED8: LTRBR37G-4R4S-0125-0; LED 120X120 LTRB R37G RGB
Q1, Q2, Q3, Q4, Q7: SSM3K15ACT,L3F; DFN65P100X50-3L
Q5, Q6: SSM3J56ACT,L3F; DFN65P100X50-3L
R1, R4, R5, R8, R11, R13, R18, R20, R23, R25, R30, R32, R35, R37, R42, R44, R50, R58: 240R 1%; RESC0603X03L
R2, R12, R24, R36: 150R 1%; RESC0603X03L
R3, R14, R26, R38, R51, R52, R53: 1.5k 1%; RESC0603X03L
R6, R17, R29, R41, R49, R55, R59: 18k 1%; RESC0603X03L
R7, R15, R16, R19, R27, R28, R31, R39, R40, R43: 1k 1%; RESC0603X03L
R9, R10, R21, R22, R33, R34, R45, R46, R47, R48, R54, R56, R57, R62: 0R 1%; RESC0603X03L
R60: 10k 1%; RESC0603X03L
R61: OPT; RESC0603X03L
R63: 33R 1%; RESC0603X03L
TP1, TP2, TP3, TP4, TP5, TP6, TP7, TP8, TP9, TP10, TP11, TP12, TP13, TP14, TP15, TP16, TP17, TP18, TP19, TP20, TP21, TP22, TP23, TP24, TP25, TP26, TP27, TP28, TP29, TP30, TP31: Testpoint 0.5mm; TP_0.50mm
U1, U2: TLV74033PDQNR; X2SON-DFN
U3, U4, U5: TTP232-CA6; SOT95P285X126-6L
U6, U7: SPK0641HT4H-1; MIC_SPK0641HT4H-1
U8: Ambient Light Sensor Module R01; ABLS-R01-AMBIENT LIGHT SENSOR MODULE
U9: TLV74018PDQNR; X2SON-DFN
U10: OV02740-H34A-Z; BGA34C53P7X5_386X292X388
U11: TLV74012PDQNR; X2SON-DFN
U12: TLV74028PDQNR; X2SON-DFN
U13: ECS-2520MV-240-BN-TR; Oscillator_ECS-2520MV

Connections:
AGND: C28.2, R62.1, U10.B7, U10.C1
AVDD: C28.1, R57.2, TP30.TP, U9.3, U10.A1, U10.C4, U10.C7, U10.E1
BAT_FCH_LED: J1.7, LED1.1
BAT_LOW_LED: J1.9, LED2.1
CAMERA_DISABLE: J17.3, LED6.1
CAMERA_ENABLE: J1.6, J17.5, LED5.1, R58.1, TP16.TP
CAM_EN: J16.2, TP13.TP, U4.3
CAM_~DIS: J17.6, TP12.TP, U4.1
CAM_~EN: J16.4, J17.1
CAP_CAM_DIS: R21.1, U4.6
CAP_CAM_DIS_PAD: C13.1, J15.1, R21.2
CAP_CAM_EN: R22.1, U4.4
CAP_CAM_EN_PAD: C14.1, J14.1, R22.2
CAP_MIC_DIS: R34.1, U5.4
CAP_MIC_DIS_PAD: C19.1, J19.1, R34.2
CAP_MIC_EN: R33.1, U5.6
CAP_MIC_EN_PAD: C18.1, J18.1, R33.2
CAP_WIFI_DIS: R9.1, U3.6
CAP_WIFI_DIS_PAD: C8.1, J11.1, R9.2
CAP_WIFI_EN: R10.1, U3.4
CAP_WIFI_EN_PAD: C9.1, J10.1, R10.2
CM_D: J17.2, R28.1
CM_~SD: J17.7, R27.1
CSI_CLK_N: J1.37, U10.D5
CSI_CLK_P: J1.35, U10.E5
CSI_D0_N: J1.31, U10.D4
CSI_D0_P: J1.29, U10.E4
CSI_D1_N: J1.23, U10.D6
CSI_D1_P: J1.25, U10.E6
DOVDD: C26.1, C35.1, R51.2, R52.2, R53.2, R54.2, TP27.TP, U10.A3, U10.C6, U11.3, U13.1, U13.4
DVDD: C27.1, R56.2, TP28.TP, U10.A7, U10.D3, U10.E7
GLOBAL_PWM: J1.10, R4.2, R13.2, R25.2, R37.2
GND: C1.2, C2.2, C3.2, C4.2, C5.2, C6.2, C7.2, C8.2, C9.2, C10.2, C11.2, C12.2, C13.2, C14.2, C15.2, C16.2, C17.2, C18.2, C19.2, C20.2, C21.2, C22.2, C23.2, C24.2, C25.2, C26.2, C27.2, C29.2, C30.2, C31.2, C32.2, C33.2, C34.2, C35.2, J1.5, J1.21, J1.26, J1.27, J1.30, J1.32, J1.33, J1.36, J1.38, J1.39, J1.MT, J12.3, J13.4, J16.3, J17.4, J20.3, J21.4, J22.1, Q1.2, Q2.2, Q3.2, Q4.2, Q7.2, R6.1, R17.1, R29.1, R41.1, R59.2, R62.2, TP8.TP, TP31.TP, U1.2, U1.5, U2.2, U2.5, U3.2, U4.2, U5.2, U6.5, U6.6, U6.7, U6.8, U7.3, U7.5, U7.6, U7.7, U7.8, U8.2, U8.3, U8.4, U9.2, U9.5, U10.B1, U10.C2, U10.C5, U10.D7, U10.E3, U11.2, U11.5, U12.2, U12.5, U13.2
LSNS_SCL: J1.4, U8.6
LSNS_SDA: J1.2, U8.5
MIC_D: J21.2, R40.1
MIC_DISABLE: J21.3, LED8.1, R50.1
MIC_EN: J20.2, TP17.TP, U5.1
MIC_~DIS: J21.6, TP18.TP, U5.3
MIC_~EN: J20.4, J21.1
MIC_~SD: J21.7, R39.1
MLED_EN: J21.5, LED7.1, TP21.TP
NetC24_1: C24.1, R54.1, U9.1
NetC25_1: C25.1, C30.1, C34.1, Q6.3, TP26.TP, U9.4, U11.4, U12.3, U12.4
NetC29_1: C29.1, R56.1, U11.1
NetC31_1: C31.1, R57.1, U12.1
NetJ1_1: J1.1, R47.2, R48.1, TP22.TP
NetJ1_3: J1.3, R45.2, R46.1, TP23.TP
NetLED1_2: LED1.2, R3.1
NetLED1_3: LED1.3, R1.1
NetLED1_4: LED1.4, R2.1
NetLED2_2: LED2.2, R8.1
NetLED2_3: LED2.3, R5.1
NetLED2_4: LED2.4, R7.1
NetLED3_2: LED3.2, R14.1
NetLED3_3: LED3.3, R11.1
NetLED3_4: LED3.4, R12.1
NetLED4_2: LED4.2, R20.1
NetLED4_3: LED4.3, R18.1
NetLED4_4: LED4.4, R19.1
NetLED5_2: LED5.2, R26.1
NetLED5_3: LED5.3, R23.1
NetLED5_4: LED5.4, R24.1
NetLED6_2: LED6.2, R32.1
NetLED6_3: LED6.3, R30.1
NetLED6_4: LED6.4, R31.1
NetLED7_2: LED7.2, R38.1
NetLED7_3: LED7.3, R35.1
NetLED7_4: LED7.4, R36.1
NetLED8_2: LED8.2, R44.1
NetLED8_3: LED8.3, R42.1
NetLED8_4: LED8.4, R43.1
NetQ1_1: Q1.1, R4.1, R6.2
NetQ1_3: Q1.3, R1.2, R2.2, R3.2, R5.2, R7.2, R8.2, TP4.TP
NetQ2_1: Q2.1, R13.1, R17.2, TP9.TP
NetQ2_3: Q2.3, R11.2, R12.2, R14.2, R18.2, R19.2, R20.2, TP10.TP
NetQ3_1: Q3.1, R25.1, R29.2, TP14.TP
NetQ3_3: Q3.3, R23.2, R24.2, R26.2, R30.2, R31.2, R32.2, TP15.TP
NetQ4_1: Q4.1, R37.1, R41.2, TP19.TP
NetQ4_3: Q4.3, R35.2, R36.2, R38.2, R42.2, R43.2, R44.2, TP20.TP
NetQ5_1: Q5.1, R49.1, R50.2, TP25.TP
NetQ6_1: Q6.1, Q7.3, R55.2, TP29.TP
NetQ7_1: Q7.1, R58.2, R59.1
NetR45_1: R45.1, U6.1
NetR46_2: R46.2, U7.1
NetR47_1: R47.1, U6.2
NetR48_2: R48.2, U7.2
NetR60_1: R60.1, U10.A4
NetR63_1: R63.1, U13.3
SNS_FSIN: J1.14, U10.B3
SNS_GPIO: J1.22, U10.A5
SNS_PWDNB: J1.12, U10.B2
SNS_SCL: J1.24, U10.B6
SNS_SDA: J1.20, U10.B5
SNS_SID: R53.1, U10.A6
SNS_STROBE: J1.18, R60.2
SNS_VH: C33.1, U10.D1
SNS_VN: C32.1, U10.D2
SNS_XSHDN: J1.11, R51.1, U10.C3
SNS_XSHDN2: R52.1, U10.A2
SNS_XVCLK: R61.1, R63.2, U10.B4
VCC3.3: C5.1, C10.1, C11.1, C15.1, C16.1, C20.1, C21.1, J12.6, J13.8, J16.6, J17.8, J20.6, J21.8, R15.2, R16.2, R27.2, R28.2, R39.2, R40.2, TP3.TP, U2.1
VCC5.0: C2.1, C3.1, C4.1, C6.1, J1.28, J1.34, J1.40, Q6.2, R55.1, TP2.TP, U1.3, U1.4, U2.3, U2.4
VCCA3.3: C1.1, C7.1, C12.1, C17.1, Q5.2, R49.2, TP1.TP, TP5.TP, U1.1, U3.5, U4.5, U5.5, U8.1
VCC_MIC: C22.1, C23.1, Q5.3, TP24.TP, U6.3, U6.4, U7.4
WIFI_EN: J12.2, TP7.TP, U3.3
WIFI_~DIS: J13.6, TP6.TP, U3.1
WIFI_~EN: J12.4, J13.1
WI_D: J13.2, R16.1
WI_~SD: J13.7, R15.1
WLED_DIS: J13.3, LED4.1
WiFi_ENABLE: J1.8, J13.5, LED3.1, TP11.TP
XVCLK: J1.16, R61.2

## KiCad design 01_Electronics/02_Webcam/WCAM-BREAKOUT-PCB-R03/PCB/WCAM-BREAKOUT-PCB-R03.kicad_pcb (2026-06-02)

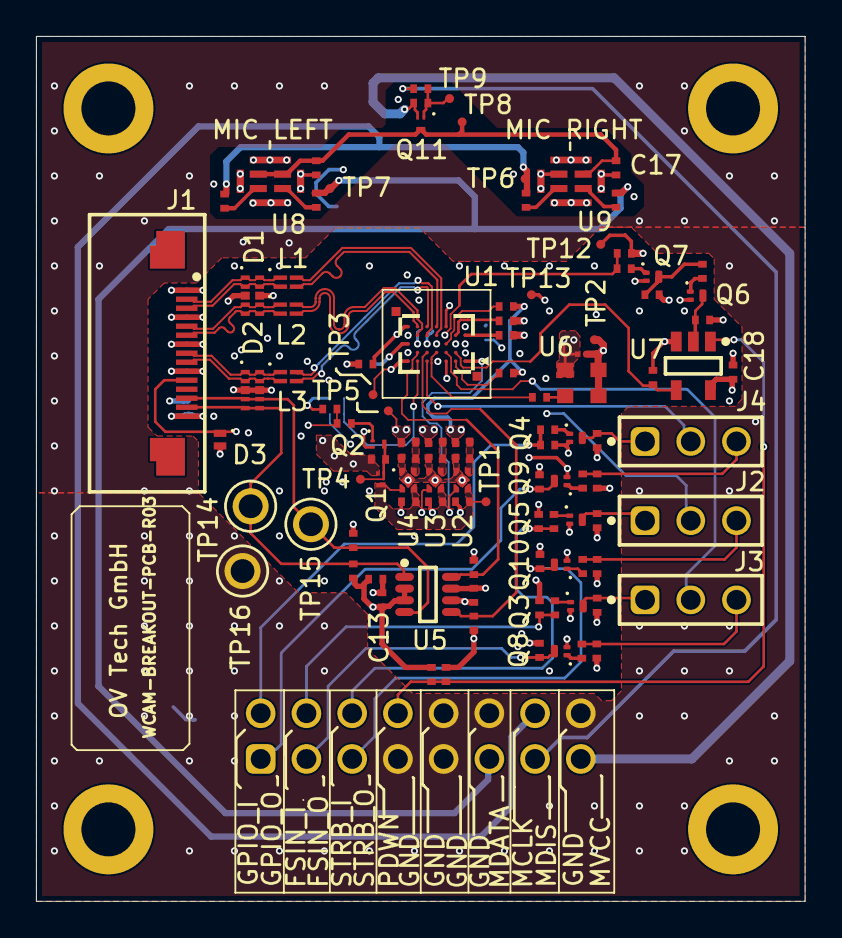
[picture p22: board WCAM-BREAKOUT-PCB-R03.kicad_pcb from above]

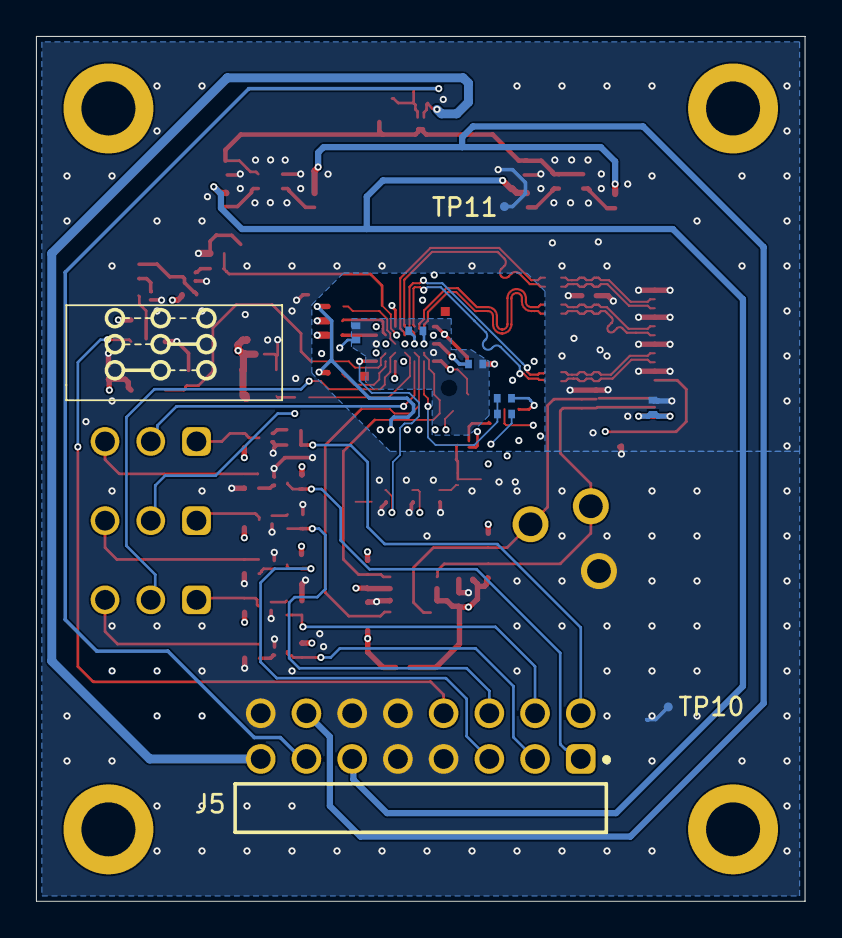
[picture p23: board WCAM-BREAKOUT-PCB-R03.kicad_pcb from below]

Board: 4 copper layers, 42.7 x 48.1 mm, 114 parts (9 on the bottom side), 73 nets.

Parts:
C1, C2, C3, C6, C7, C8, C9, C10, C11, C12: 1µF 25V; CAPC1005X06L
C4, C5, C16, C17: 470nF 25V; CAPC1005X06L
C13, C14, C18: 100nF 16V; CAPC1005X06L
C15: 470nF 10V; CAPC0603X03L
D1, D2: ESD7504MUTAG; QFN50P250X100X55-10L
D3: PESD5V5C1UL; DFN65P100X50-2N
J1: F32Q-1A7H1-11015; FFC 15pol 0.5mm F32Q-1A7H1-11015
J2, J3, J4: 61300311121; BOARD TO BOARD Pinheader WE_61300311121
J5: 61301621021; BOARD TO BOARD Pinheader WE_61301621021
L1, L2, L3: 90Ohm 100mA; CAF-50P85X64-4N
Q1, Q11: SSM3J56ACT,L3F; DFN65P100X50-3L
Q2: SSM3K15ACT,L3F; DFN65P100X50-3L
Q3, Q4, Q5, Q6, Q7, Q8, Q9, Q10: PMZ130UNEYL; DFN65P98X50-3N
R1, R2, R4, R9, R44, R45: 0Ohm 1%; RESC1005X04L
R3, R6: 15k 1%; RESC1005X04L
R5, R47: 240R 1%; RESC1005X04L
R7, R8, R16, R17, R18, R48, R49: 1.5k 1%; RESC1005X04L
R10, R11, R12, R13: 3.3k 1%; RESC1005X04L
R14: 27R 1%; RESC1005X04L
R15, R24, R25, R26, R29, R30, R31, R39, R40, R41: 10k 1%; RESC1005X04L
R19, R22, R28, R33, R34, R35: 22k 1%; RESC1005X04L
R20, R21, R23, R27, R32, R36, R37, R38: 100R 1%; RESC1005X04L
R42, R43: 33 1%; RESC1005X04L
R46: 18k 1%; RESC1005X04L
TP1, TP2, TP3, TP4, TP5, TP6, TP7, TP8, TP9, TP10, TP11, TP12, TP13: Testpoint 0.5mm; TP_0.50mm
TP14, TP15, TP16: 4952; TP_Keystone_4952
U1: OV02740-H34A-Z; BGA34C53P7X5_386X292X388
U2: TLV74018PDQNR; X2SON-DFN
U3: TLV74012PDQNR; X2SON-DFN
U4: TLV74028PDQNR; X2SON-DFN
U5: TCA9416DDFR; TSOP65P280X110-8N
U6: ECS-2520MV-240-BN-TR; Oscillator_ECS-2520MV
U7: 74LVC1G08GV; SOT95P275X110-5N
U8, U9: SPK0641HT4H-1; MIC_SPK0641HT4H-1

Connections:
AGND: C3.2, R9.2, U1.B7, U1.C1
AVDD: C3.1, R4.1, TP5.TP, U1.A1, U1.C4, U1.C7, U1.E1, U2.3
CAM_I2C_SCL: D2.4, D2.7, J1.13, R11.1, TP15.TP, U5.4
CAM_I2C_SDA: D2.5, D2.6, J1.14, R10.1, TP14.TP, U5.1
CAM_nRST: D3.1, J1.11, R5.1, R6.1
CON_CSI_CLK_N: D2.1, D2.10, J1.8, L3.1
CON_CSI_CLK_P: D2.2, D2.9, J1.9, L3.4
CON_CSI_D0_N: D1.1, D1.10, J1.2, L1.1
CON_CSI_D0_P: D1.2, D1.9, J1.3, L1.4
CON_CSI_D1_N: D1.4, D1.7, J1.5, L2.1
CON_CSI_D1_P: D1.5, D1.6, J1.6, L2.4
CSI_CLK_N: L3.2, U1.D5
CSI_CLK_P: L3.3, U1.E5
CSI_D0_N: L1.2, U1.D4
CSI_D0_P: L1.3, U1.E4
CSI_D1_N: L2.2, U1.D6
CSI_D1_P: L2.3, U1.E6
DOVDD: C5.1, C14.1, C15.1, C18.1, R1.1, R7.1, R12.2, R13.2, R16.2, R17.2, R18.2, R19.2, R22.2, R34.2, R48.1, R49.1, TP2.TP, U1.A3, U1.C6, U3.3, U5.7, U6.1, U6.4, U7.5
DVDD: C4.1, R2.1, R32.2, R33.2, TP3.TP, U1.A7, U1.D3, U1.E7
FSIN_3V3_INPUT: J5.4, R20.2, R24.2
FSIN_3V3_OUTPUT: J5.3, Q8.3, R29.1
GND: C1.2, C2.2, C4.2, C5.2, C6.2, C7.2, C8.2, C9.2, C10.2, C11.2, C12.2, C13.2, C14.2, C15.2, C16.2, C17.2, C18.2, D1.3, D1.8, D2.3, D2.8, D3.2, J1.1, J1.4, J1.7, J1.10, J5.7, J5.9, J5.10, J5.12, J5.16, Q2.2, Q3.2, Q4.2, Q5.2, Q6.2, Q7.2, Q8.2, Q9.2, Q10.2, R6.2, R8.1, R9.1, R15.1, R24.1, R25.1, R26.1, R28.1, R33.1, R39.1, R40.1, R41.1, TP10.TP, TP11.TP, TP12.TP, TP13.TP, TP16.TP, U1.B1, U1.C2, U1.C5, U1.D7, U1.E3, U2.2, U2.5, U3.2, U3.5, U4.2, U4.5, U5.6, U6.2, U7.3, U8.5, U8.6, U8.7, U8.8, U9.3, U9.5, U9.6, U9.7, U9.8
GPIO_3V3_INPUT: J5.2, R21.2, R25.2
GPIO_3V3_OUTPUT: J5.1, Q9.3, R30.1
MIC_CLK: J5.14, R44.2, R45.1, TP6.TP
MIC_DATA: J5.11, R42.2, R43.1, TP7.TP
MIC_DISABLE: J5.13, R47.1
NetC1_1: C1.1, C7.1, C11.1, Q1.3, TP1.TP, U2.4, U3.4, U4.3, U4.4
NetC2_1: C2.1, R1.2, U2.1
NetC8_1: C8.1, R2.2, U3.1
NetC12_1: C12.1, R4.2, U4.1
NetJ2_1: J2.1, Q5.3, R18.1
NetJ2_3: J2.3, R38.1, R41.2
NetJ3_1: J3.1, Q3.3, R16.1
NetJ3_3: J3.3, R36.1, R39.2
NetJ4_1: J4.1, Q4.3, R17.1
NetJ4_3: J4.3, R37.1, R40.2
NetQ1_1: Q1.1, Q2.3, R3.2, TP4.TP
NetQ2_1: Q2.1, R5.2
NetQ3_1: Q3.1, R20.1
NetQ4_1: Q4.1, R21.1
NetQ5_1: Q5.1, R23.1
NetQ6_1: Q6.1, R27.1
NetQ7_1: Q7.1, R32.1
NetQ7_3: Q7.3, R22.1, R27.2
NetQ8_1: Q8.1, R36.2
NetQ9_1: Q9.1, R37.2
NetQ10_1: Q10.1, R38.2
NetQ11_1: Q11.1, R46.1, R47.2, TP9.TP
NetR14_2: R14.2, U6.3
NetR42_1: R42.1, U8.1
NetR43_2: R43.2, U9.1
NetR44_1: R44.1, U8.2
NetR45_2: R45.2, U9.2
NetR48_2: R48.2, U1.C3
NetR49_2: R49.2, U1.A2
PWDNB_EXT: J5.8, R34.1, R35.1, U7.1
PWDNB_POWER_SUPPLY: Q6.3, R19.1, U7.2
SCL_1V8: R12.1, U1.B6, U5.8
SDA_1V8: R13.1, U1.B5, U5.5
SNS_FSIN: J3.2, U1.B3
SNS_GPIO: J4.2, U1.A5
SNS_PWDNB: R28.2, U1.B2, U7.4
SNS_SID: R7.2, R8.2, U1.A6
SNS_STROBE: J2.2, U1.A4
SNS_VH: C9.1, U1.D1
SNS_VN: C10.1, U1.D2
SNS_XVCLK: R14.1, U1.B4
STROBE_3V3_INPUT: J5.6, R23.2, R26.2
STROBE_3V3_OUTPUT: J5.5, Q10.3, R31.1
VCC3.3: C6.1, C13.1, J1.15, Q1.2, R3.1, R10.2, R11.2, R15.2, R29.2, R30.2, R31.2, R35.2, U5.2, U5.3
VCC3.3MIC: J5.15, Q11.2, R46.2
VCC_MIC: C16.1, C17.1, Q11.3, TP8.TP, U8.3, U8.4, U9.4

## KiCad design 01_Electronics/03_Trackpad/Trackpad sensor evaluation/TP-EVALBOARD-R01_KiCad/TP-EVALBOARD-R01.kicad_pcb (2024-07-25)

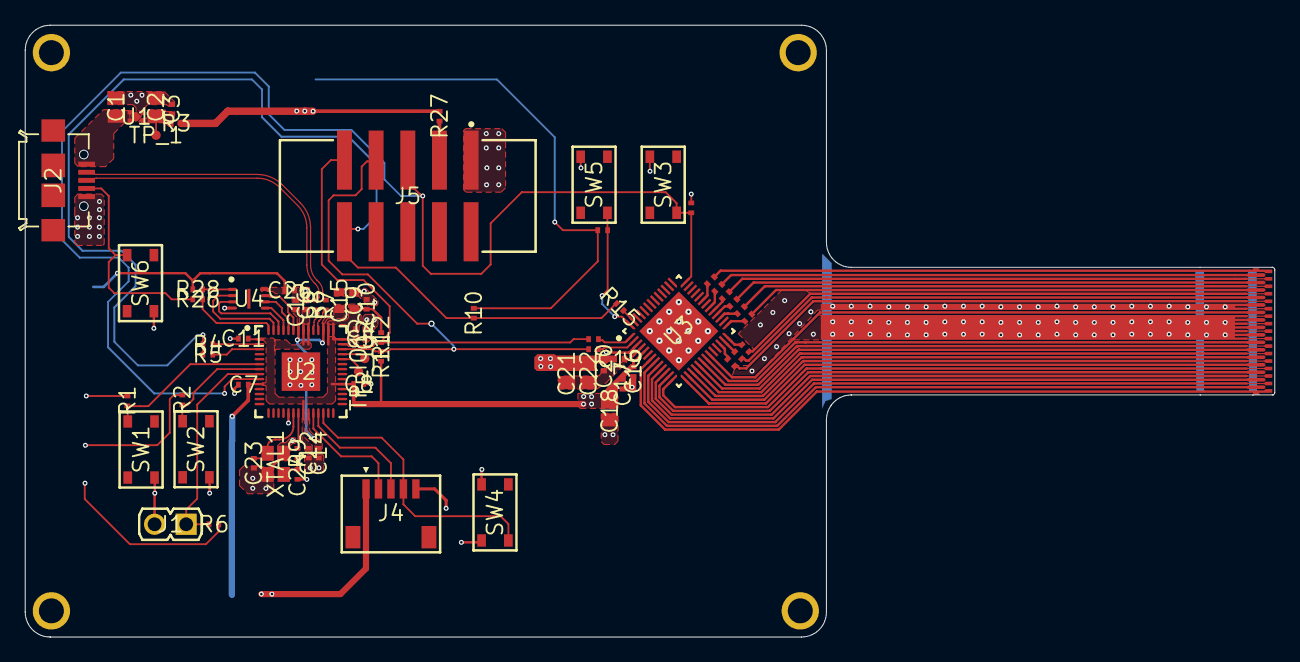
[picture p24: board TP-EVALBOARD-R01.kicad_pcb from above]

Board: 2 copper layers, 100.3 x 49.1 mm, 77 parts (0 on the bottom side), 72 nets.

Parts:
C1, C2, C18, C21, C22: CAPC2012X14L
C3, C4, C5, C6, C7, C8, C10, C11, C12, C13, C14, C16, C17, C19, C20, C23, C24, C25, C26: CAPC1005X06L
C9, C15: CAPC1608X10L
J1: Pin Header 2Pol 61300211121
J2: USB-TYPE MICRO B_629105136821
J3: WIRE-TO-BOARD_RECEPTABLE_FH35C-33S-0.3SHW(50)
J4: Wire-to-Board SM05B-SRSS-TB
J5: WIRE-TO-BOARD_WE_61231020621
MP1, MP2, MP3, MP4: MP_2MM
R1, R2, R3, R4, R5, R6, R7, R8, R9, R10, R11, R12, R13, R14, R15, R16, R17, R18, R19, R20, R21, R22, R23, R24, R25, R26, R27, R28: RESC1005X04L
SW1, SW2, SW3, SW4, SW5, SW6: SW_TACT_PTS815 SJM 250 SMTR LFS
TP_1: TP_0.75mm
TP_IO1, TP_IO2: TP_0.75mm
U1: X2SON-DFN
U2: QFN40P700X700X90_HS-57L
U3: QFN40P600X600X80_HS-53M
U4: QFN50P300X200X60_HS-9L
XTAL1: XTAL_ECX-2236B2_250X200X60

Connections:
3V3: C4.1, C5.1, C6.1, C7.1, C8.1, C9.1, C10.1, C11.1, C12.1, C16.1, C17.1, C18.1, C26.1, J4.1, R1.1, R2.1, R3.2, R6.2, R10.2, R11.2, R12.2, R24.2, R27.1, R28.1, U2.1, U2.10, U2.22, U2.33, U2.42, U2.43, U2.44, U2.48, U2.49, U3.5, U4.8
3V3_REG: C2.1, C3.1, R3.1, TP_1.TP, U1.1
/USB_BOOT_IN: J2.4, R26.1, SW6.1
GND: C1.2, C2.2, C3.2, C4.2, C5.2, C6.2, C7.2, C8.2, C9.2, C10.2, C11.2, C12.2, C13.2, C14.2, C15.2, C16.2, C17.2, C18.2, C19.2, C20.2, C21.2, C22.2, C23.2, C24.2, C25.2, C26.2, J1.2, J2.5, J3.15, J3.16, J3.17, J3.18, J3.19, J3.20, J3.21, J3.23, J3.24, J4.5, J5.1, SW1.4, SW2.4, SW3.4, SW4.3, SW4.4, SW5.4, SW6.4, U1.2, U1.5, U2.19, U2.57, U3.3, U3.53, U4.4, XTAL1.2, XTAL1.4
GPIO4_RND: R1.2, SW1.1, U2.6
GPIO5_RND: R2.2, SW2.1, U2.7
GPIO6_SNAP_DOME: J1.1, R6.1, U2.8
GPIO7_IQS_nRST: C25.1, J5.5, SW3.1, U2.9, U3.39
I2C_SCL: J5.9, R12.1, R14.1, U2.41
I2C_SDA: J5.7, R11.1, R13.1, U2.40
IQS_RDY: J5.10, R4.2, R5.2, R10.1, R15.1
IQS_RX0: J3.25, R16.2
IQS_RX1: J3.33, R25.2
IQS_RX2: J3.31, R22.2
IQS_RX3: J3.29, R20.2
IQS_RX4: J3.27, R18.2
IQS_RX5: J3.26, R17.2
IQS_RX6: J3.28, R19.2
IQS_RX7: J3.32, R23.2
IQS_RX8: J3.30, R21.2
IQS_SW_IN: R24.1, SW5.1, U3.52
IQS_TX0: J3.14, U3.20
IQS_TX1: J3.12, U3.18
IQS_TX2: J3.2, U3.8
IQS_TX3: J3.4, U3.10
IQS_TX4: J3.6, U3.12
IQS_TX5: J3.8, U3.14
IQS_TX6: J3.10, U3.16
IQS_TX7: J3.22, U3.21
IQS_TX8: J3.1, U3.7
IQS_TX9: J3.3, U3.9
IQS_TX10: J3.5, U3.11
IQS_TX11: J3.7, U3.13
IQS_TX12: J3.9, U3.15
IQS_TX13: J3.11, U3.17
IQS_TX14: J3.13, U3.19
NetC24_1: C24.1, R9.1, XTAL1.3
NetJ5_3: J5.3, R27.2
NetR4_1: R4.1, U2.2
NetR5_1: R5.1, U2.3
NetR13_2: R13.2, U3.2
NetR14_2: R14.2, U3.1
NetR15_2: R15.2, U3.51
NetR16_1: R16.1, U3.24
NetR17_1: R17.1, U3.25
NetR18_1: R18.1, U3.26
NetR19_1: R19.1, U3.27
NetR20_1: R20.1, U3.29
NetR21_1: R21.1, U3.30
NetR22_1: R22.1, U3.31
NetR23_1: R23.1, U3.32
NetR25_1: R25.1, U3.34
NetTP_IO1_TP: TP_IO1.TP, U2.38
NetTP_IO2_TP: TP_IO2.TP, U2.39
QSPI_SCLK: U2.52, U4.6
QSPI_SD0: U2.53, U4.5
QSPI_SD1: U2.55, U4.2
QSPI_SD2: U2.54, U4.3
QSPI_SD3: U2.51, U4.7
QSPI_SS: R26.2, R28.2, U2.56, U4.1
RUN: J4.4, SW4.1, U2.26
SWCLK: J4.2, U2.24
SWDIO: J4.3, U2.25
USB_D_N: J2.2, R7.1
USB_D_P: J2.3, R8.1
USB_MCU_D_N: R7.2, U2.46
USB_MCU_D_P: R8.2, U2.47
VBUS: C1.1, J2.1, U1.3, U1.4
VREG: C19.1, C20.1, C21.1, C22.1, U3.4
VREG_VOUT: C13.1, C14.1, C15.1, U2.23, U2.45, U2.50
XIN: C23.1, U2.20, XTAL1.1
XOUT: R9.2, U2.21

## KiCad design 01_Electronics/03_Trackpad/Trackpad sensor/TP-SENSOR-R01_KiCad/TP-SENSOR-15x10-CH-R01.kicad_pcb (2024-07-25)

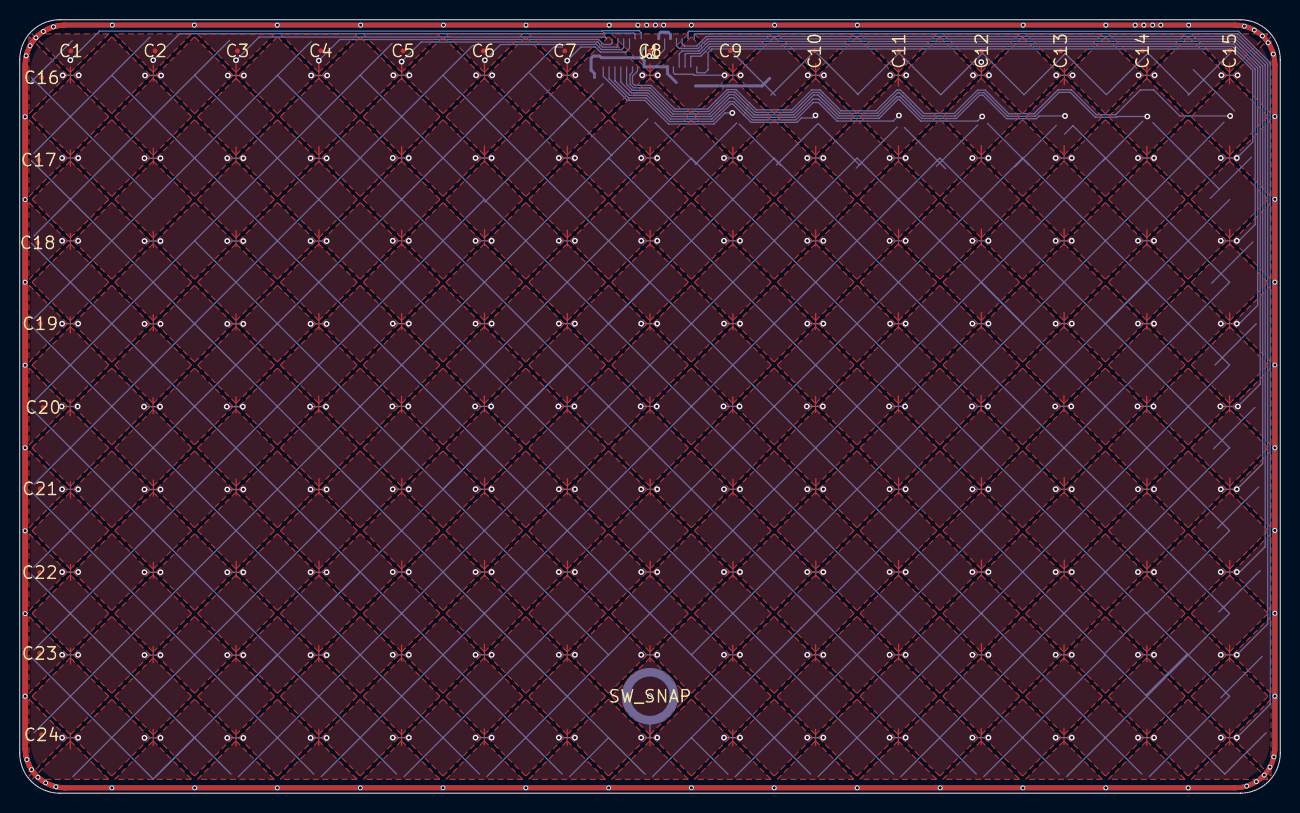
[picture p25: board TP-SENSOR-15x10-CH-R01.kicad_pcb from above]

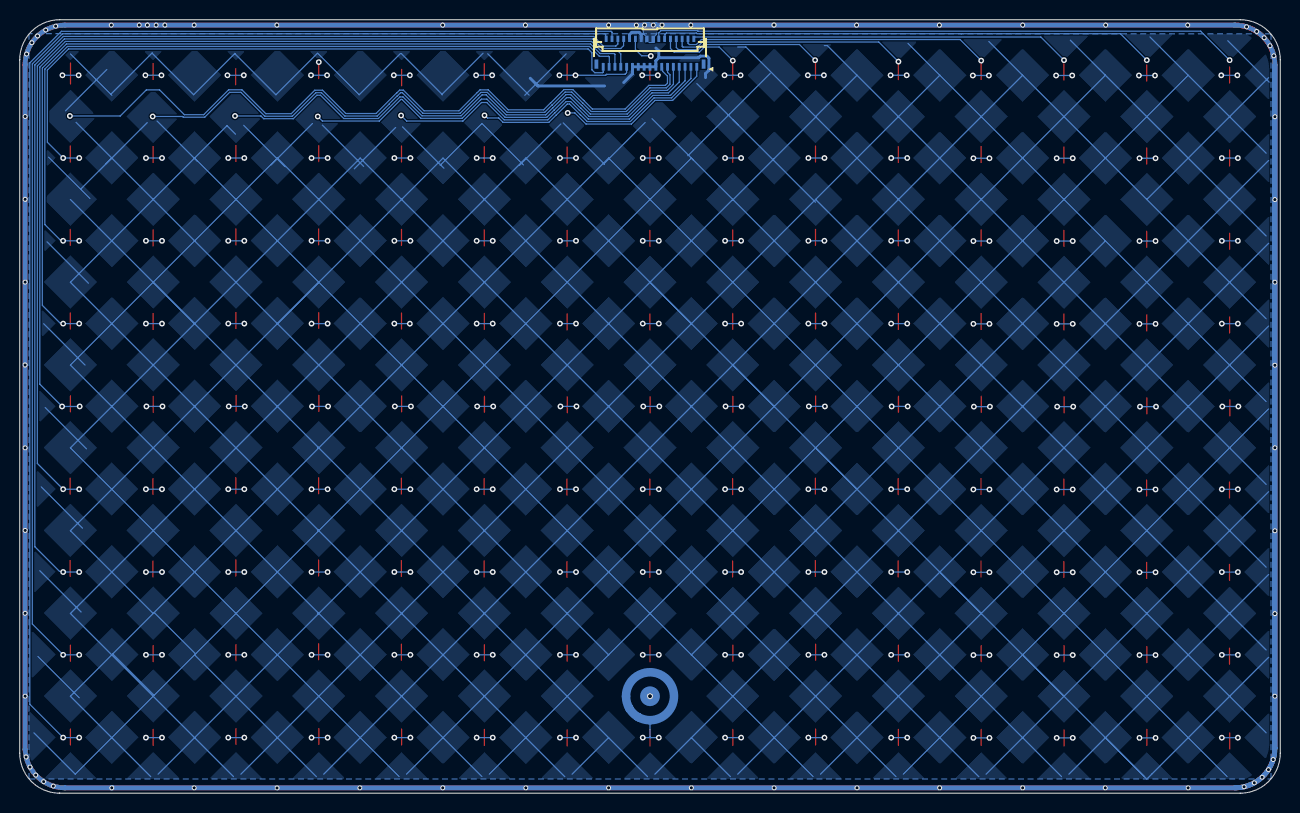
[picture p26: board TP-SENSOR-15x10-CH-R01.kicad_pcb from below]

Board: 2 copper layers, 129.4 x 79.4 mm, 26 parts (2 on the bottom side), 26 nets.

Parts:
C1, C2, C3, C4, C5, C6, C7, C8, C9, C10, C11, C12, C13, C14, C15: CAP_TRACKPAD_TX_CLM
C16, C17, C18, C19, C20, C21, C22, C23, C24: CAP_TRACKPAD_RX_ROW
J1: FFC 33pol 0.3mm FH35C-33S-0.3SHW
SW_SNAP: SNAPDOME_RCG05200N

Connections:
EMI-GND: J1.16, J1.18
GND: J1.15, J1.17, J1.19, J1.20, J1.21, J1.23, J1.24
TP-SENS-RX0: C16.RX_ROW, J1.25
TP-SENS-RX1: C17.RX_ROW, J1.33
TP-SENS-RX2: C18.RX_ROW, J1.31
TP-SENS-RX3: C19.RX_ROW, J1.29
TP-SENS-RX4: C20.RX_ROW, J1.27
TP-SENS-RX5: C21.RX_ROW, J1.26
TP-SENS-RX6: C22.RX_ROW, J1.28
TP-SENS-RX7: C23.RX_ROW, J1.32
TP-SENS-RX8: C24.RX_ROW, J1.30, SW_SNAP.1
TP-SENS-TX0: C1.TX_CLM, J1.14
TP-SENS-TX1: C2.TX_CLM, J1.12
TP-SENS-TX2: C3.TX_CLM, J1.2
TP-SENS-TX3: C4.TX_CLM, J1.4
TP-SENS-TX4: C5.TX_CLM, J1.6
TP-SENS-TX5: C6.TX_CLM, J1.8
TP-SENS-TX6: C7.TX_CLM, J1.10
TP-SENS-TX7: C8.TX_CLM, J1.22, SW_SNAP.2
TP-SENS-TX8: C9.TX_CLM, J1.1
TP-SENS-TX9: C10.TX_CLM, J1.3
TP-SENS-TX10: C11.TX_CLM, J1.5
TP-SENS-TX11: C12.TX_CLM, J1.7
TP-SENS-TX12: C13.TX_CLM, J1.9
TP-SENS-TX13: C14.TX_CLM, J1.11
TP-SENS-TX14: C15.TX_CLM, J1.13

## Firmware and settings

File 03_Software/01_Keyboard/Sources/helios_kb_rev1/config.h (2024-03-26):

// Copyright 2023 ThomasL (@ThommyL34)
// SPDX-License-Identifier: GPL-2.0-or-later

#pragma once

/*
 * Feature disable options
 *  These options are also useful to firmware size reduction.
 */

/* disable debug print */
//#define NO_DEBUG

/* disable action features */
//#define NO_ACTION_LAYER
//#define NO_ACTION_TAPPING
//#define NO_ACTION_ONESHOT

#define BACKLIGHT_PIN GP25
//#define BACKLIGHT_LEVELS 10
//#define BACKLIGHT_LIMIT_VAL 255
//#define BACKLIGHT_ON_STATE 1

//#define BACKLIGHT_DEFAULT_ON TRUE
//#define BACKLIGHT_DEFAULT_LEVEL BACKLIGHT_LEVELS
//#define RGBLIGHT_DEFAULT_HUE 169
#define RGBLIGHT_LIMIT_VAL 255
#define WS2812_DI_PIN GP23
#define RGBLED_NUM 82
//#define HAL_USE_PWM TRUE
//#define RP_PWM_USE_PWM4 TRUE
//#define BACKLIGHT_PWM_DRIVER PWMD4

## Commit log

2024-03-02 Initial commit keyboard and webcam PCB
    [00 Block Diagram.SchDoc, 01 Touch Sensing Keys.SchDoc, 02 Sensors.SchDoc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]
2024-03-24 Added Keyboard and Webcam electronics in KiCAD format
    [01 Touch Sensing Keys.kicad_sch, 02 Sensors.kicad_sch, 0603 Chip SMD LED (1.6x0.8mm).STEP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]
2024-03-25 Adding webcam sensor breakout board and keyboard mechanics
    [BOM_WCAM-BREAKOUT-PCB-R01.xlsx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]
2024-04-23 Update README.md
    Added the description of the KB-PCB Rev2
2024-07-17 Upload for Trackpad data
    This commit contains all data for the trackpad sensor and evaluation board.
    [61231020621.stp, 61300211121 (rev1).stp, 629105136821.stp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]
2026-06-02 Added breakout boards for developing
    Added altium designer and KiCad projects:
    * FMC-USB-PHY-BOARD-R02
    * WCAM-BREAKOUT-PCB-R03
    * KiCad_WCAM-BREAKOUT-PCB-R03
    * KiCad_FMC-USB-PHY-BOARD-R02
    [4952--3DModel-STEP-630548.STEP, 61300311121.stp, 61301621021.stp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]

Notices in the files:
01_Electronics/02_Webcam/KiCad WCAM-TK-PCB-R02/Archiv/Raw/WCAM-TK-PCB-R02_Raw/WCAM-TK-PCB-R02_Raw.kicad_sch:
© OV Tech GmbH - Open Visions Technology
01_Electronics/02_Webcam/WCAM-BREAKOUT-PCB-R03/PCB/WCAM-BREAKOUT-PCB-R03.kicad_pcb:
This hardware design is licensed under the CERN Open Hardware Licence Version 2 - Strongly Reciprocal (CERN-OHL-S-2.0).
